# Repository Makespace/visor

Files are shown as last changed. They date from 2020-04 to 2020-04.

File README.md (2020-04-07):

# Makespace Visor

The documents covering the regulation, design and production of the Makespace Visor

For the high-level overview of this activity, see https://web.makespace.org/visor/

* _Requirements_ – The device specification, regulations and risk assessments
* _Design Files_ – The delve mask design files
* _Materials_ – The materials, BOM, and data sheets
* _Production_ – Manufacturing Standard Operating Procedure (SOP), Training and Worker/Batch Tracking
* _Documentation_ – The accompanying documentation and labelling for shipping

The _Manufacturing SOP_ and _Manufacturing SOP checklist_ documents found in the _production_ directory are the key documents describing the whole process, and the place to start if you want to learn about the activity.

The _Workstation single point lessons_ ppt is also useful to get a feel for the activities that need to be performed.

The _requirements_ directory is good reading for context on how the essential safety requirements mandated in regulations are fulfilled by the design and documentation. This is what is required when the UK government relaxed the rules on PPE for hospitals from ‘at least CE marked’ to ‘meet essential safety requirements’.

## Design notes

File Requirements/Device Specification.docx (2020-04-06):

# General Device Description & Intended Purpose

https://www.ncbi.nlm.nih.gov/pmc/articles/PMC5015006/

“Face shields are personal protective equipment devices that are used by many workers (e.g., medical, dental, veterinary) for protection of the facial area and associated mucous membranes (eyes, nose, mouth) from splashes, sprays, and spatter of body fluids. Face shields are generally not used alone, but in conjunction with other protective equipment and are therefore classified as adjunctive personal protective equipment. “

# Specifications for Product

Product Requirements

1. Face shield must have a single elasticated strap.
2. Doffing can be accomplished with a single hand.
3. Face shields must fit snugly to afford a good seal to the forehead area - forehead contact at least width of eyes. Contact surface soft foam or rubber, to reduce slippage during wearing.
4. Visors must not significantly distort vision. Normal font size text should be readable whilst wearing them.
5. Face shields should reach down to the chin and to the point of the ear, and seal to the forehead.
6. The face should be sufficiently rigid to not move around (creating noise or distortion) whilst walking.
7. The edges and corners or both the headband and visor should not be sharp such that they could rip gloves or cause injury. The staples must not touch the skin.
8. The visor should have sufficient clearance to the face for goggles and a face mask to be worn comfortably.
9. Visors should be resistant to fogging, either through coatings or ventilation.
10. The face shield is single use so does need to be sterilisable or resistant to cleaning products

For reference: https://docs.google.com/document/d/15k20PMe14_XQa-8kTA2G7nSIrF1bGSpc90_GM9H8yNI/edit

Cambridge University Hospitals NHS Foundation Trust Page 1 of 2 Prescription for Face Shield to be used during Coronavirus outbreak

Clinical Engineering Innovation Medical Physics and Clinical Engineering

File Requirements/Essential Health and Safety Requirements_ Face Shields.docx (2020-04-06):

# Essential Health and Safety Requirements: Face Shields

1. Purpose

Face shields are NOT a medical device:

https://assets.publishing.service.gov.uk/government/uploads/system/uploads/attachment_data/file/284505/Borderlines_with_medical_devices.pdf

Masks intended to protect the wearer, they are regulated as personal protective equipment and need to meet the regulations covering PPE products:

https://eur-lex.europa.eu/legal-content/EN/TXT/?uri=CELEX:32016R0425

In the current coronavirus outbreak regulations have been temporarily suspended to fast-track supplies of PPE to NHS staff and protect companies hit by COVID-19. PPE equipment is allowed to be placed on the market providing protection against COVID-19 which lack the CE mark onto the market provided products meet essential safety requirements.

https://www.gov.uk/government/news/regulations-temporarily-suspended-to-fast-track-supplies-of-ppe-to-nhs-staff-and-protect-companies-hit-by-covid-19

2. Scope

This document sets out the Essential Health and Safety Requirements in Annex II of the REGULATION (EU) 2016/425 OF THE EUROPEAN PARLIAMENT AND OF THE COUNCIL of 9 March 2016 on personal protective equipment and repealing Council Directive 89/686/EEC for face shields produced and manufactured by CEI for use within Addenbrookes to help prevent coronavirus (COVID-19)

3. Annex II: Essential Health and Safety Requirements

In addition to any of the measures specified in this document, a full risk assessment will be performed in order to identify the risks which apply to this PPE. This will include not only the intended use of the PPE, but also the reasonably foreseeable uses and where applicable, the health and safety of persons other than the user.

Essential Health and Safety Requirement | Method of fulfilment | Additional documentation (if applicable)

1. GENERAL REQUIREMENTS APPLICABLE TO ALL PPE
PPE must provide adequate protection against the risks against which it is intended to protect. | Face shields are designed to protect the face and eyes from liquid droplets that may contain viral particles. The plastic visors cover the full face and are impermeable to water. | Design Documentation
1.1. Design principles 1.1.1. Ergonomics PPE must be designed and manufactured so that, in the foreseeable conditions of use for which it is intended, the user can perform the risk-related activity normally whilst enjoying appropriate protection of the highest level possible. | The face shields are made of clear plastic to allow the user full visibility to perform their activities whilst providing appropriate protection. | Requirements Specification Design Documentation User Feedback / Clinical prescription
1.1.2. Levels and classes of protection 1.1.2.1. Optimum level of protection The optimum level of protection to be taken into account in the design is that beyond which the constraints imposed by the wearing of the PPE would prevent its effective use during the period of exposure to the risk or the normal performance of the activity. | The face shields are designed to be as large as possible to cover the entire face, without impacting activities. The flexible plastic allows for a close fit around the face and the foam along the top prevents droplets entering from above. Further attempts to make the design more fitted would limit the number of clinicians who it would fit and restrict normal activities. | Requirements Specification Design Documentation Risk File
1.1.2.2. Classes of protection appropriate to different levels of risk Where differing foreseeable conditions of use are such that several levels of the same risk can be distinguished, appropriate classes of protection must be taken into account in the design of the PPE. | Face shields are designed to meet the user requirements for use as specified by hospital guidance. Where specified in the hospital guidance and training documents additional or different PPE will be worn | Requirements Specification Design Documentation
1.2. Innocuousness of PPE 1.2.1. Absence of inherent risks and other nuisance factors PPE must be designed and manufactured so as not to create risks or other nuisance factors under foreseeable conditions of use. | Face masks are designed so that only a foam strip makes contact with the user's forehead. This is to maximise comfort and increase compliance. Face shields are designed to be similar to current PPE used by clinical staff in the hospital. | Requirements Specification Design Documentation User Feedback / Clinical Prescription
1.2.1.1. Suitable constituent materials The materials of which the PPE is made, including any of their possible decomposition products, must not adversely affect the health or safety of users. | Appropriate selection of materials and suppliers. Non toxic biocompatible materials selected. Materials will only make contact with non-broken skin. | Material Data sheets and supplier information
1.2.1.2. Satisfactory surface condition of all PPE parts in contact with the user Any part of the PPE that is in contact or is liable to come into contact with the user when the PPE is worn must be free of rough surfaces, sharp edges, sharp points and the like which could cause excessive irritation or injuries. | Plastic shields will be cut using a laser cutter and checked for rough or sharp edges. If found these will be removed by an appropriate method (e.g. x-acto knife) | Manufacturing Work Instruction - Quality Check
1.2.1.3. Maximum permissible user impediment Any impediment caused by PPE to the actions to be carried out, the postures to be adopted and sensory perceptions shall be minimised. Furthermore, use of the PPE must not engender actions which might endanger the user. | Face shields will be designed to be similar to those that clinicians are already familiar with wearing. There shall be no increased impediments. Elastic straps will not be too tight that users will feel the need to reposition their face shields during use. They will not be too loose that the face shield could slip down. | Requirements Specification Device Design Documentation Risk File User Feedback / Clinical Prescription Device Verification and Validation
1.3. Comfort and effectiveness 1.3.1. Adaptation of PPE to user morphology PPE must be designed and manufactured in such a way as to facilitate its correct positioning on the user and to remain in place for the foreseeable period of use, bearing in mind ambient factors, the actions to be carried out and the postures to be adopted. For this purpose, it must be possible to adapt the PPE to fit the morphology of the user by all appropriate means, such as adequate adjustment and attachment systems or the provision of an adequate range of sizes. | The use of compressible foam strip and elastic strap allow the face shields to fit comfortably on users of varying morphology | Device Design Documentation Risk File Device Verification and Validation
1.3.2. Lightness and strength PPE must be as light as possible without prejudicing its strength and effectiveness. PPE must satisfy the specific additional requirements in order to provide adequate protection against the risks for which it is intended and PPE must be capable of withstanding environmental factors in the foreseeable conditions of use. | The face shields are designed to protect users against liquid droplets. In typical use it is not anticipated that they will come into contact with any large mechanical forces. The plastic is therefore as thin as possible to be as light as possible and flex easily around the users head.The plastic will not shatter if a foreseeable force is applied. | Risk File Device Design Documentation Materials Data Sheets
1.3.3. Compatibility of different types of PPE intended for simultaneous use If the same manufacturer places on the market several PPE models of different types in order to ensure the simultaneous protection of adjacent parts of the body, they must be compatible. | User feedback - Sadaf & Christine feedback that it fits over goggles, glasses, masks | Device Verification and Validation
1.3.4. Protective clothing containing removable protectors Protective clothing containing removable protectors constitutes PPE and shall be assessed as a combination during conformity assessment procedures. | n/a

1.4. Manufacturer's instructions and information

In addition to the name and address of the manufacturer, the instructions that must be supplied with the PPE must contain all relevant information on:

A. instructions for storage, use, cleaning, maintenance, servicing and disinfection. Cleaning, maintenance or disinfectant products recommended by manufacturers must have no adverse effect on the PPE or the user when applied in accordance with the relevant instructions;
B. performance as recorded during relevant technical tests to check the levels or classes of protection provided by the PPE;
C. where applicable, accessories that may be used with the PPE and the characteristics of appropriate spare parts;
D. where applicable, the classes of protection appropriate to different levels of risk and the corresponding limits of use;
E. where applicable, the month and year or period of obsolescence of the PPE or of certain of its components;
F. where applicable, the type of packaging suitable for transport;
G. the significance of any markings (see point 2.12);
H. the risk against which the PPE is designed to protect;
I. the reference to this Regulation and, where applicable, the references to other Union harmonisation legislation;
J. the name, address and identification number of the notified body or bodies involved in the conformity assessment of the PPE;
K. references to the relevant harmonised standard(s) used, including the date of the standard(s), or references to the other technical specifications used;
L. the internet address where the EU declaration of conformity can be accessed.

The information referred to in points (i), (j), (k) and (l) need not be contained in the instructions supplied by the manufacturer if the EU declaration of conformity accompanies the PPE.

Instructions for Use (on outer packaging of each face shield).

Label Content (on face shield)

Manufacturer's Instructions and Information

2. ADDITIONAL REQUIREMENTS COMMON TO SEVERAL TYPES OF PPE
2.3. PPE for the face, eyes and respiratory system Any restriction of the user's face, eyes, field of vision or respiratory system by the PPE shall be minimised. The screens for those types of PPE must have a degree of optical neutrality that is compatible with the degree of precision and the duration of the activities of the user. If necessary, such PPE must be treated or provided with means to prevent misting-up. Models of PPE intended for users requiring sight correction must be compatible with the wearing of spectacles or contact lenses. | Face shields are transparent to allow for full visibility. Testing on volunteers to ensure that they do not fog up or restrict vision | Requirements Specification Device Design Documentation Risk file Materials Data sheets Device Verification and Validation

3.10.2. Protection against cutaneous and ocular contact

PPE intended to prevent the surface contact of all or part of the body with substances and mixtures which are hazardous to health or with harmful biological agents must be capable of preventing the penetration or permeation of such substances and mixtures and agents through the protective integument under the foreseeable conditions of use for which the PPE is intended.

To this end, the constituent materials and other components of those types of PPE must be chosen or designed and incorporated so as to ensure, as far as possible, complete leak-tightness, which will allow where necessary prolonged daily use or, failing this, limited leak-tightness necessitating a restriction of the period of wear.

Where, by virtue of their nature and the foreseeable conditions of their use, certain substances and mixtures which are hazardous to health or harmful biological agents possess high penetrative power which limits the duration of the protection provided by the PPE in question, the latter must be subjected to standard tests with a view to their classification on the basis of their performance. PPE which is considered to be in conformity with the test specifications must bear a marking indicating, in particular, the names or, in the absence of the names, the codes of the substances used in the tests and the corresponding standard period of protection. The manufacturer's instructions must also contain, in particular, an explanation of the codes (if necessary), a detailed description of the standard tests and all appropriate information for the determination of the maximum permissible period of wear under the different foreseeable conditions of use.

Face shields are designed to protect the face and eyes from liquid droplets that may contain viral particles. The plastic visors cover the full face and are impermeable to water.

Risk File

Monitoring compliance with and the effectiveness of this document

This process forms part of a quality system accredited to International Standard EN ISO 9001:2015, EN ISO 13485:2016 and BS 70000:2017. The effectiveness of the process will be monitored in accordance with the methods given in the Quality Manual (CE-QS-QAM-4).

Equality and diversity statement

This document complies with the Cambridge University Hospitals NHS Foundation Trust service equality and diversity statement.

Disclaimer

It is your responsibility to check against the electronic library that this printed out copy is the most recent issue of this document.

Document management

Approval:
MDAG approval:
Owning department: | Clinical Engineering Innovation
Author(s): | Sarah Greasley
Pharmacist: | n/a
File name: | Device Verification and Validation
Supersedes: | n/a
Version number: | 1.0 | Review date: | n/a
Local reference: | | Document ID:

Cambridge University Hospitals NHS Foundation Trust Essential Health and Safety Requirements: Face Shields

Clinical Engineering Innovation Medical Physics and Clinical Engineering

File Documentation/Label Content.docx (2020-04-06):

# Label Content

# Product Label

- For each product

Full Face Shield

Personal Protective Equipment

Non-sterile, disposable

MS-yy/mm/dd-’Initials’

Clinical Engineering, Box 152, Addenbrooke's Hospital, Cambridge, CB2 0QQ

# Shipping Label

- For each box of product

Full Face Shield x 24

Packed on: yy/mm/dd

By: “Initials”

Manufactured for: Clinical Engineering, Box 152, Addenbrooke's Hospital, Cambridge, CB2 0QQ

Shipping Address

# Non-Conformance Label

- An additional label for boxes of product where some or all of the products carry an increased risk of contamination with COVID-19 due to some non-conformance with the Manufacturing SOP

Full Face Shield x 24

Packed on: yy/mm/dd

Health & Safety Notice:

DO NOT UNPACK UNTIL packing date + 5 days

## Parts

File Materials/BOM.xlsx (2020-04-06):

Material | Thickness/width (mm) | Size (mm) each | Notes | Suppliers / status / risk | Order Status | Example Link | Cost |  | 1K cost | 2K cost
PLASTIC
PET | 0.18 | 330x230 | 0.1-0.5 closer to 0.18mm the better), at least 330x230mm |  |  |  |  |  | 0.76 | 0.38
ELASTIC
Roll of elastic | 25 | 0.345metres | Latex free difficult to source - best to check with suppliers |  |  | https://www.amazon.co.uk/dp/B079TMHSZP/ref=pe_3187911_189395841_TE_3p_dp_1?pldnSite=1 | Donated but worth £10.89 |  | 0.25 | 0.25
FOAM - PU adhesive backed
PU Foam | 25x25mm | 225 | ~30kgs/m^3 |  |  | https://www.efoam.co.uk/acoustic-soundproofing-foam.php | £185 for 3 x 100 cm x 200 cm sheet plus ~120 delivery |  | 0.205 | 0.205
Plastic packaging
Plastic bags to wrap finished PPE |  |  | 305mm x 406mm self sealing 1100 on order |  |  | https://www.amazon.co.uk/gp/product/B01AQO7PRU/ref=ppx_yo_dt_b_asin_title_o00_s00?ie=UTF8&psc=1 | £6.67 / 100 | 73.37 | 0.0667 | 0.103385
OTHER
Staples | 26/6 | 2 per | Standard Rapid 26/6 - stationary weight staples |  |  | https://www.amazon.co.uk/gp/product/B004VUV8ZQ/ref=ppx_yo_dt_b_asin_title_o02_s00?ie=UTF8&psc=1 | £1.63 / 5000 |  | 0.0042
Boxes for shipment to Hospital |  | 2020-01-24 | they sit flat, so 330x230x26mm each, though could nest to be 330x230x13 average
Packing tape |  | 1m | 6 x 65m x 50mm clear packing tape |  |  | https://www.amazon.co.uk/gp/product/B01ABXS3ZO/ref=ppx_yo_dt_b_asin_title_o02_s00?ie=UTF8&psc=1 | £6.07 / 360m
Labels
Anitfog |  |  |  |  |  | https://www.amazon.co.uk/Cressi-Anti-Fog-Spray-60-ML/dp/B004TRQAEU | £7.98 / 2 bottles
Disinfectant
Bleach | 1 bottle | 1 litre | Domestos - donated |  |  | https://www.epa.gov/pesticide-registration/list-n-disinfectants-use-against-sars-cov-2 | £1 per bottle? |  | 0.005
Cleaner
Multipurpose Cleaner | 1 bottle | 5 litre | 5 Star Multi Purpose Cleaner 5 Litre (https://www.amazon.co.uk/gp/product/B00PFT0MZ4/ref=ppx_yo_dt_b_asin_title_o08_s00?ie=UTF8&psc=1) |  |  | https://www.amazon.co.uk/gp/product/B00PFT0MZ4/ref=ppx_yo_dt_b_asin_title_o08_s00?ie=UTF8&psc=1 | £5.62 |  | 0.00562
Cleaning Cloths
Center feed cloths | 2 rolls | 350 sheet |  |  |  | https://www.amazon.co.uk/gp/product/B00BTHABGG/ref=ppx_yo_dt_b_asin_title_o06_s00?ie=UTF8&psc=1 | £30.78/2 rolls |  | 0.03078
gloves |  |  |  |  |  |  |  |  | 0.027
visors
masks
 |  |  |  |  |  |  | £40/50 |  | 0.04
overalls
 |  |  |  |  |  |  | £5 each |  | 0.05
Reference:
https://discourse.southlondonmakerspace.org/t/3d-printing-laser-cutting-medical-face-shields-may-become-a-thing-imminently-lets-be-ready/16736/9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
https://www.delve.com/assets/documents/Open-Source-Face-Shield-Drawing.pdf
Clear Shield | 1 | £0.76
Elastic Headband | 1 | £0.25
Brow Foam | 1 | £0.20
Staples | 4 | £0.01
Plastic Bag | 1 | £0.07
Label | 1 | £0.04
Shipping Box | 2020-01-10 | £0.00
Batch sheet | 2020-01-10 | £0.01
Shipping label | 2020-01-10 | £0.01
 |  | £1.35 | Full cost - assumes costs of all material purchased and 1K shields manufactured
2K visor costs
Clear Shield | 1 | £0.38
Elastic Headband | 1 | £0.00
Brow Foam | 1 | £0.20
Staples | 4 | £0.02
Plastic Bag | 1 | £0.10
Label | 1 | £0.04
Shipping Box | 2020-01-10 | £0.00
Batch sheet | 2020-01-10 | £0.01
Shipping label | 2020-01-10 | £0.01
 |  | £0.77 | Full cost - assumes costs of all material purchased and 2K shields manufactured
Manufacturing Materials
Gloves |  | £0.03
Masks |  | £0.04
Overalls |  | £0.05
Cleaning materials |  | £0.01
Disinfecting materials |  | £0.01
Cleaning cloths |  | £0.03
Sundries (Ducktape etc) |  | £0.03
 |  | £0.18 | Nominal cost - assumes material used up to make 1K or 2K shields
 |  | £1.54 | Cost per shield for 1K shields
 |  | £0.95 | Cost per shield for 2K shields

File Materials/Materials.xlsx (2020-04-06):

Purpose: | Document materials used. Where Risk File highlights risks associated with material choice, this document relates those risks with evidence from the data sheet that the risk has/has not been controlled.
Component | Selected Material | DataSheet in folder? | Risk ID | Risk Control Measures | Documentation of risk control | Link
Visor | Polyester film (PET) | No | n/a
Foam | Open celled polyurethane foam | Yes | FV06 | Medical grade foam, tested on users for 4hrs with no adverse effects, | Data sheet, Design verification & validation | https://www.efoam.co.uk/foam-for-face-masks-shields-visors-ppe.php
 |  | Yes | FV07 | Medical grade foam, tested on users for 4hrs with no adverse effects, | Data sheet, Design verification & validation
Elastic | Woven loom elastic, 25mm, black | Yes | FV15 | Product confirmed by manufacturer to contain latex in elastic but not in covering for elastic. Risk controlled through product labelling. | Data sheet, Product Labels | https://www.williamgee.co.uk/shop/woven-loom-elastic-25mm/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
 |  | Yes | FV16 | Product confirmed by manufacturer to contain latex in elastic but not in covering for elastic. Risk controlled through product labelling. | Data sheet, Product Labels
 |  | Yes | FV17 | Product confirmed by manufacturer to contain latex in elastic but not in covering for elastic. Risk controlled through product labelling. | Data sheet, Product Labels

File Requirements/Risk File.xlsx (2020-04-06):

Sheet: Title
Medical Physics and Clinical Engineering |  |  |  | Addenbrookes Hospital
Clinical Engineering / R&D
Risk File |  |  |  | CE-ER-FRM-22
 |  | Product Identification | DELVE Visor
 |  | Document Q-Pulse reference
 |  | Doc. Name | Risk File - Delve Visor
 |  | Mandatory Supporting Documents | Q-Pulse reference
 |  | Risk Management Process
 |  | Risk Plan
 |  | Risk Report
 | Product description and intended use
 | Transparent visor covering the face, held in place by an elastic band, and cushioned on the forehead by a foam strip. The visor is considered to be PPE for use by clinical staff in close contact with patients who may have or definitely have COVID-19. The visor: - prevents droplets containing virus being projected onto the skin and mucous membranes of the user's face - reduces probability that direct contact is made with the face by patients with COVID-19 - prevents an asymptomatic, but infected, user projecting particles onto patients. The visor does not prevent small aerosol particles that come around the edges of the visor being entrained in the user's in-breath, and is therefore not considered to provide complete protection and shoudl be usefd tgeter with other appropriate PPE.
Cambridge University Hospitals NHS Foundation Trust |  |  |  |  | Page 1 of 4
This document complies with the Cambridge University Hospitals NHS Foundation Trust service Equality and Diversity statement and must be read in conjunction with Addenbrookes Hospital Policies & Procedures. It is your responsibility to check against the electronic library that this printed out copy is the most recent issue of this document. All changes required should be submitted via Q-Pulse Document module (Change request).
Filename: 008_Risk Evaluation Table
Document No.: CE-ER-FRM-15 |  |  | Version No.: 5 | Active on Q-Pulse & Published

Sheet: Revision Table
Document History
Date | Identification | Description | Name
26/03/2020 | 1.0 | Created | AB

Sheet: Risk Evaluation Criteria
CUH Risk management strategy and policy 2019-2019
 | CUH Risk management strategy and policy 2019-2020
Source | CUH Risk management strategy and policy 2019-2020, http://merlin/Lists/DMSRecords/DispRecordTabsDoc.aspx?ID=18427
Adaptations | The risk scoring matrix and grading system has been adapted to enable the CEI team to better track and manage risks that are yet to be determined, or cannot be determined.
Notes | Risk evaluation is for injury or damage to the health of people, or damage to property or the environment, and does include risks surrounding data security. It should NOT consider project or financial impacts. These should instead be considered in the Project Viability Assessment.
 | Risk Evaluation
 | Severity Score |  | Likelihood Score |  |  |  |  |  |  | Grading Risk
 |  |  | 1 | 2 | 3 | 4 | 5 | TBD | CBD | 1-3 | Low risk | No action required
 |  |  | Rare | Unlikely | Possible | Likely | Almost Certain | To be determined | Cannot be determined | 4-6 | Moderate risk | Risk reduction if practicable
 | 1 | Negligible | 1 | 2 | 3 | 4 | 5 | 25 | 25 | 8-12 | High risk | Risk reduction if practicable, cost benefit analysis required for risks that cannot be practibably lowered
 | 2 | Minor | 2 | 4 | 6 | 8 | 10 | 25 | 25 | 15-25 | Significant risk | Unnacceptable risk
 | 3 | Moderate | 3 | 6 | 9 | 12 | 15 | 25 | 25 | TBD | To be determined | Activities required to define risk likelihood or severity
 | 4 | Major | 4 | 8 | 12 | 16 | 20 | 25 | 25 | CBD | Can't be determined | Treat as unnacceptable and define control measures, or justify lower risk score
 | 5 | Catastrophic | 5 | 10 | 15 | 20 | 25 | 25 | 25
 | TBD | To be determined | 25 | 25 | 25 | 25 | 25 | 25 | 25
 | CBD | Cannot be determined | 25 | 25 | 25 | 25 | 25 | 25 | 25
 | Likelihood Score
 |  | 1 | 2 | 3 | 4 | 5
 | Descriptor | Rare | Unlikely | Possible | Likely | Almost Certain
 | Frequency | This will probably never happen/recur | Do not expect it to happen/recur but it is possible | Might happen or recur occasionally | Will probably happen/recur but it is not a persisting issue | Will undoubtedly happen/recur,possibly frequently
 | Severity Score
 |  | 1 | 2 | 3 | 4 | 5
 | Descriptor | Negligible | Minor | Moderate | Major | Catastrophic
 | Impact on the safety of patients, staff or public (physical/psychological harm) | Minimal injury requiring no/minimal intervention or treatment. | Minor injury or illness, requiring minor intervention. Increase in length of hospital stay by 1-3 days Requiring time off work for >3 days | Moderate injury requiring professional intervention. Requiring time off work for 4-14 days Increase in length of hospital stay by 4-15 days RIDDOR/agency reportable incident An event which impacts on a small number of patients. | Major injury leading to long-term incapacity/disability. Increase in length of hospital stay by >15 days. Mismanagement of patient care with longterm effects. Requiring time off work for >14 days | Incident leading to death. Multiple permanent injuries or irreversible health effects. An event which impacts on a large number of patients.
 | Quality of treatment | Peripheral element of treatment or service suboptimal Informal complaint/inquiry | Overall treatment or service suboptimal Single failure to meet internal standards | Treatment or service has significantly reduced in effectiveness Repeated failure to meet internal standards | Non-compliance with national standards with significant risk to patients if unresolved Multiple complaints/ independent review Low performance rating Critical report | Totally unacceptable level or quality of treatment/service Gross failure of patient safety if findings not acted on Inquest/ombudsman inquiry Gross failure to meet national standards
 | Personal information | No risk to confidential staff or patient data | Occassional/one-off cases of personal data exposure within CUH | Data exposure within CUH | Public exposure of personal data Exposure of personal data to entities who may use that data against the best interest of the person to whom the data belongs | Large scale public exposure of personal data Exposure of personal data to entities who will use that data against the best interest of the person to whom the data belongs
 | Envrionmental impact | Minimal or no impact on the environment | Minor impact on environment | Moderate impact on environment | Major impact on environment | Catastrophic impact on environment
 | Environmental impact | Minimal or no impact on the environment | Minor impact on environment | Moderate impact on environment | Major impact on environment | Catastrophic impact on environment

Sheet: Benefit Evaluation Criteria
008_Risk Evaluation Table
 | Benefit Evaluation Criteria
Source | Developed by CEI
Adaptations | n/a
Notes | Benefit evaluation is for assessing impact on positive impact on clinical outcome, the patient’s quality of life, outcomes related to diagnosis, positive impact from diagnostic devices on clinical outcomes, or positive impact on public health or patient management. It should NOT consider project or financial impacts. These should instead be considered in the Project Viability Assessment.
 | Risk Evaluation
 | Benefit Size Score |  | Certainty Score |  |  |  |  | Grading Risk
 |  |  | 1 | 2 | 3 | 4 | 5 | 15-25 | Large, clear benefit
 |  |  | Very unlikely to be realised | Unlikely | Possible | Likely | Almost Certain | 2020-10-12 | Reasonable benefit
 | 1 | Negligible | 1 | 2 | 3 | 4 | 5 | 2020-05-09 | Small benefit
 | 2 | Minor | 2 | 4 | 6 | 8 | 10 | 2020-01-04 | Very little benefit
 | 3 | Moderate | 3 | 6 | 9 | 12 | 15
 | 4 | High | 4 | 8 | 12 | 16 | 20
 | 5 | Very High | 5 | 10 | 15 | 20 | 25
 | Likelihood Score
 |  | 1 | 2 | 3 | 4 | 5
 | Descriptor | Rare | Unlikely | Possible | Likely | Almost Certain
 | Frequency | Possible but quite unlikely outcome of the project/extremely uncertain outcome of the project | Possible outcome of the project, but uncertain | Possible outcome of the project | A likely outcome of the project | Will undoubtedly happen as an outcome of the project if completed successfully
 | Impact Score
 |  | 1 | 2 | 3 | 4 | 5
 | Descriptor | Negligible | Minor | Moderate | High | Very High
 | Medical Benefit | No measurable impact on medical outcomes No measurable impact on patient experience Minor anecdotal benefit | Minor measurable impact on medical outcomes Minor measurable impact on patient experience Moderate anecdotal benefit | Moderate measurable impact on medical outcomes Moderate measurable impact on patient experience Large anecdotal benefit (e.g. patients happy to engage with a home treatment method where they otherwise wouldn't) | Significant measurable impact on key medical outcomes Significant measurable impact on patient experience | Measurable life-saving impact
 | Scale of impact | Hospital, short term or one-off Less than 100 patients per year | Hospital Hundreds of patients per year | Hospital or regional Thousands of patients per year | National 10s of thousands of patients per year | International 100s of thousands of patients affected per year
 | Clinical benefit | No measurable impact | Minor increase in number of patients treated for a given resource (e.g. reduced hospital stay Minor decrease in resource required to treat a given number of patients (lower cost per intervention, reduction in consultant time per appointment) Minor improvement in service quality (e.g. speed of diagnosis, error reduction) | Moderate increase in number of patients treated for a given resource (e.g. reduced hospital stay Moderate decrease in resource required to treat a given number of patients (lower cost per intervention, reduction in consultant time per appointment) Moderate improvement in service quality (e.g. speed of diagnosis, error reduction) | Large increase in number of patients treated for a given resource (e.g. reduced hospital stay Large decrease in resource required to treat a given number of patients (lower cost per intervention, reduction in consultant time per appointment) Large improvement in service quality (e.g. speed of diagnosis, error reduction) | Transformative increase in number of patients treated for a given resource (e.g. reduced hospital stay Transformative decrease in resource required to treat a given number of patients (lower cost per intervention, reduction in consultant time per appointment) Transformative improvement in service quality (e.g. speed of diagnosis, error reduction)

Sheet: Overall Benefit Risk
008_Risk Evaluation Table
Benefit Risk Summary
Source | Developed by CEI
 | Overall Benefit: | 25
 | Residual Risk: | 10
 | Summary of benefit: | This device would enable Addenbrookes staff to access face visors when they otherwise would not have access. The project will supply 100,000 disposable face visors, where otherwse the trust would have none. Face visors are a key piece of PPE required to protect staff from liquid droplets transmitting COVID-19 from impacting mucous membranes and skin of the face.
 | Summary of risk: | There is a small residual risk that COVID-19 could be transmitted from manufacturer to staff, due to the short timeframe between manufacture and use. COVID-19 can survive on plastic surfaces fro at least 3 days, potentially longer. There is a small risk that someone with a severe latex allergy may be severely harmed through use of this product.
 | Actions summary: | If applicable summarise intended actions (for example, to reduce the risk)
Optional: Benefit-risk summary for current state-of-the-art
Source | If the device being assessed is intended to replace/improve upon the current state of the art, it can strengthen the benefit-risk analysis to compare it to the benefit-risk profile of the device representing the current state-of-the-art or best practice. In situations where there is no obvious comparative device, this type of analysis may not be appropriate. “State-of-the-art” embodies what is currently and generally accepted as good practice in technology and medicine. The state of the art does not necessarily imply the most technologically advanced solution.
 | Overall Benefit: | 0
 | Residual Risk: | 0
 | Summary of benefit: | Summarise the overall clinical/medical benefit being delivered
 | Summary of risk: | Summarise the overall clinical/medical risk being considered
 | Actions summary: | If applicable summarise intended actions (for example, to reduce the risk)
 | NOT APPLICABLE - product proposal is due to absence of availability of state-of-the-art

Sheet: Device Benefit Evaluation
008_Risk Evaluation Table
Benefit Evaluation Table for medical and clinical benefits associated with the medical device
Source | Developed by CEI
 | Overall Benefit: | 25 | Evaluate overall residual medical/clinical benefit. This can be estimated as the largest single RPN score.
S = severity, L = likelihood, RPN = Risk Priority Number
Unique ID for hazard plus control measure - useful for referencing hazards in other documents | Brief note explaining benefit | Brief note explaining consequence of benefit | Define any investigatory activities/follow up actions when it is too early to define impact/likelihood | Impact | Likelihood | Score
ID | Benefit | Consequence | Investigatory activities required | S | L | RPN
FV01 | Face visors are available for staff requiring them. Without this project, staff will go without face visors. | Reduction of staff risk in contracting COVID-19 |  | 5 | 5 | 25
 |  |  |  |  |  | 0
 |  |  |  |  |  | 0
 |  |  |  |  |  | 0
 |  |  |  |  |  | 0
 |  |  |  |  |  | 0
 |  |  |  |  |  | 0
 |  |  |  |  |  | 0
 |  |  |  |  |  | 0
 |  |  |  |  |  | 0
 |  |  |  |  |  | 0
 |  |  |  |  |  | 0
 |  |  |  |  |  | 0
 |  |  |  |  |  | 0
 |  |  |  |  |  | 0
 |  |  |  |  |  | 0
 |  |  |  |  |  | 0
 |  |  |  |  |  | 0
 |  |  |  |  |  | 0
 |  |  |  |  |  | 0
 |  |  |  |  |  | 0
 |  |  |  |  |  | 0
 |  |  |  |  |  | 0
 |  |  |  |  |  | 0
 |  |  |  |  |  | 0
 |  |  |  |  |  | 0
 |  |  |  |  |  | 0
 |  |  |  |  |  | 0
 |  |  |  |  |  | 0
 |  |  |  |  |  | 0
 |  |  |  |  |  | 0
 |  |  |  |  |  | 0
 |  |  |  |  |  | 0
 |  |  |  |  |  | 0
 |  |  |  |  |  | 0
 |  |  |  |  |  | 0
 |  |  |  |  |  | 0
 |  |  |  |  |  | 0
 |  |  |  |  |  | 0
 |  |  |  |  |  | 0
 |  |  |  |  |  | 0
 |  |  |  |  |  | 0
 |  |  |  |  |  | 0
 |  |  |  |  |  | 0
 |  |  |  |  |  | 0
 |  |  |  |  |  | 0
 |  |  |  |  |  | 0
 |  |  |  |  |  | 0
 |  |  |  |  |  | 0
 |  |  |  |  |  | 0
 |  |  |  |  |  | 0
 |  |  |  |  |  | 0
 |  |  |  |  |  | 0
 |  |  |  |  |  | 0
 |  |  |  |  |  | 0
 |  |  |  |  |  | 0
 |  |  |  |  |  | 0
 |  |  |  |  |  | 0
 |  |  |  |  |  | 0
 |  |  |  |  |  | 0
 |  |  |  |  |  | 0
 |  |  |  |  |  | 0

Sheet: Device Risk Evaluation
Risk Evaluation Table for health hazards associated with the medical device that may impact users or patients
Scope: | injury or damage to the health of people, or damage to property or the environment
Source | Developed by CEI
 | Residual Risk: | 10 | Evaluate overall residual medical/clinical risk following the process described in the Risk Management Process CE-ER-PRO-14
 | Explanation: | Severity of overall risk is high, as COVID-19 could be transmitted to frontline medical staff via the PPE. However, the risks are being managed through a number of measures to make this unlikely.
S = severity, L=likelihood
Unique ID for hazard plus control measure | Brief note describing hazard | Brief note expalining impact/consequences of hazard | Severity | Likelihood | Score | Define any investigatory activities/follow up actions when it is too early to define a risk control activity | Define activities to control risk (or summarise existing evidence) | Provide a Q-Pulse reference, or location reference to the Technical File | Provide a date of completion for risk control activitie, to confim the activity has been completed | Severity | Likelihood | Score | Detail outcome - is the risk acceptable? If not, is a further risk control measure required (please enter the same hazard with a different ID and repeat the risk evaluation and control prcoess)? Alternatively, is a risk benefit analysis required? | Optional - tick if a risk/benefit is required | Please summarise the outcome of the risk/benefit analysis | If not in this document, please supply a Q-Pulse reference or location reference to the Technicla Filefor location of risk-benefit analysis
ID | Hazard | Consequence | S | L | RPN | Further activities required | Risk Control Measures | Supporting Documentation | Date carried out dd/mm/yyyy | S2 | L2 | RPN2 | Outcome | Risk/Benefit required? | Risk Benefit Outcome | Supporting Documentation2
FV01 | Viral transmission from manufacturer to user via persistence of virus on plastic visor materials | Infection of clinical staff member, who may infect other staff or patients - worst possible consequence is death | 5 | 3 | 15 | Check longevity of viable virus in literature | Process control to ensure risk of transmission from manufacturer to product is minimised | Manufacturing SOP | 29/03/2020 | 5 | 1 | 5 | No further risk reduction practicable for this design. One further risk reduction option is to identify a design that is suitable for cleaning/sterilisation on arrival on site. | Yes | Likelihood of infection through not wearing a visor is probable. The likelihood of infection from a visor subject to these process controls would be extremely rare.
FV02 | Viral transmission due to presence of virus on plastic material for visor before arrival at the manufacturing facility. Transmission to manufacturing staff, or to clinical staff. | Infection of clinical staff member, who may infect other staff or patients - worst possible consequence is death | 5 | 3 | 15 | Risk assess different material supply options | Prevention through material handling controls | Manufacturing SOP | 29/03/2021 | 5 | 1 | 5 | No further risk reduction practicable for this design. One further risk reduction option is to identify a design that is suitable for cleaning/sterilisation on arrival on site. | Yes | Likelihood of infection through not wearing a visor is probable. The likelihood of infection from a visor subject to these process controls would be extremely rare.
FV03 | Viral transmission due to presence of virus on foam material before arrival at the manufacturing facility. Transmission to manufacturing staff, or to clinical staff. | Infection of clinical staff member, who may infect other staff or patients - worst possible consequence is death | 5 | 3 | 15 | Risk assess different material supply options | Prevention through material handling controls | Manufacturing SOP | 29/03/2022 | 5 | 1 | 5 | No further risk reduction practicable for this design. One further risk reduction option is to identify a design that is suitable for cleaning/sterilisation on arrival on site. | Yes | Likelihood of infection through not wearing a visor is probable. The likelihood of infection from a visor subject to these process controls would be extremely rare.
FV04 | Viral transmission due to presence of virus on elastic material before arrival at the manufacturing facility. Transmission to manufacturing staff, or to clinical staff. | Infection of clinical staff member, who may infect other staff or patients - worst possible consequence is death | 5 | 3 | 15 | Risk assess different material supply options | Prevention through material handling controls | Manufacturing SOP | 29/03/2023 | 5 | 1 | 5 | No further risk reduction practicable for this design. One further risk reduction option is to identify a design that is suitable for cleaning/sterilisation on arrival on site. | Yes | Likelihood of infection through not wearing a visor is probable. The likelihood of infection from a visor subject to these process controls would be extremely rare.
FV05 | Viral transmission due to presence of virus on packaging material before arrival at the manufacturing facility. Transmission to manufacturing staff, or to clinical staff. | Infection of clinical staff member, who may infect other staff or patients - worst possible consequence is death | 5 | 3 | 15 | Risk assess different material supply options | Prevention through material handling controls | Manufacturing SOP | 29/03/2024 | 5 | 1 | 5 | No further risk reduction practicable for this design. One further risk reduction option is to identify a design that is suitable for cleaning/sterilisation on arrival on site. | Yes | Likelihood of infection through not wearing a visor is probable. The likelihood of infection from a visor subject to these process controls would be extremely rare.
FV06 | Foam irritates skin | Skin damage | 2 | 3 | 6 |  | Ensure material selected is appropriate for skin contact up to 4 hr | Data sheet | 2020-01-04 | 1 | 1 | 1 | Acceptable | No
FV07 | Foam irritates skin | clinical staff stop wearing mask | 5 | 2 | 10 |  | Ensure material selected is appropriate for skin contact up to 4 hrs | Data sheet | 2020-01-04 | 5 | 1 | 5 | No further risk reduction practicable | Yes | Likelihood of infection through not wearing a visor is highly likely. The likelihood of infection from a visor that is removed due to discomfort is also highly likely. Having the mask does not worsen the risk profile compared to the baseline situation.
FV08 | Droplets impact facial skin despite wearing visor | Infection, death | 5 | 2 | 10 |  | Dimensions of mask match or exceed predicate device - height above face, below face, width, extent of curvature | Design verification & validation | 2020-01-04 | 5 | 1 | 5 | No further risk reduction practicable | Yes | This design of mask provides the same or better protection than CE marked designs.
FV09 | Mask fogs up during use | clinical staff stop wearing mask | 5 | 2 | 10 | Evaluate need for anti-fog | Testing for 4hrs whilst wearing FFP3 mask | Design verification & validation | 2020-01-04 | 5 | 1 | 5 | No further risk reduction practicable | Yes | Likelihood of infection through not wearing a visor is highly likely. The likelihood of infection from a visor that is removed due to discomfort is also highly likely. Having the mask does not worsen the risk profile compared to the baseline situation.
FV10 | Mask does not fit face properly | clinical staff stop wearing mask | 5 | 2 | 10 | Initial evaluation by range of staff required - could we put a QR code on visor to a GoogleForm? | Testing with a range of different head size users | Design verification & validation | 2020-01-04 | 5 | 1 | 5 | No further risk reduction practicable | Yes | Likelihood of infection through not wearing a visor is highly likely. The likelihood of infection from a visor that is removed due to discomfort is also highly likely. Having the mask does not worsen the risk profile compared to the baseline situation.
FV12 | Mask is uncomfortable by design | clinical staff stop wearing mask | 5 | 2 | 10 | Initial evaluation by range of staff required - could we put a QR code on visor to a GoogleForm? | Testing for 4hrs whilst wearing FFP3 mask | Design verification & validation | 2020-01-04 | 5 | 1 | 5 | No further risk reduction practicable | Yes | Likelihood of infection through not wearing a visor is highly likely. The likelihood of infection from a visor that is removed due to discomfort is also highly likely. Having the mask does not worsen the risk profile compared to the baseline situation.
FV13 | Mask is uncomfortable due to sharp edges or staples | clinical staff stop wearing mask | 5 | 2 | 10 |  | Quality control during manufacturing process | Manufacturing SOP | 29/03/2024 | 5 | 1 | 5 | No further risk reduction practicable | Yes | Likelihood of infection through not wearing a visor is highly likely. The likelihood of infection from a visor that is removed due to discomfort is also highly likely. Having the mask does not worsen the risk profile compared to the baseline situation.
FV14 | Non-viral infection of clinical staff by face sheild | Staff sickness - possibility of passing on to patient | 4 | 2 | 8 | Risk assess different material supply options | Prevention through material selction/storage controls | Manufacturing SOP | 29/03/2024 | 4 | 1 | 4 | Acceptable | No
FV15 | Elastic contains latex | Skin damage | 2 | 2 | 4 |  | First, try to source latex free elastic. If not possible, mitigate through selecting elastic where the latex material is enclosed thereby unlikely to come into contact with skin, and clearly label the product stating that the elastic contains latex. | Data sheet Product Labels | 2020-01-04 | 2 | 1 | 2 | Acceptable | No
FV16 | Elastic contains latex | irritates skin, clinical staff stop wearing mask | 5 | 1 | 5 |  | First, try to source latex free elastic. If not possible, mitigate through selecting elastic where the latex material is enclosed thereby unlikely to come into contact with skin, and clearly label the product stating that the elastic contains latex. | Data sheet Product Labels | 2020-01-04 | 5 | 1 | 5 | No further risk reduction practicable | Yes | Likelihood of infection through not wearing a visor is highly likely. The likelihood of infection from a visor that is removed due to discomfort is also highly likely. Having the mask does not worsen the risk profile compared to the baseline situation.
FV17 | Elastic contains latex | Severe allergic reaction | 5 | 1 | 5 |  | First, try to source latex free elastic. If not possible, mitigate through selecting elastic where the latex material is enclosed thereby unlikely to come into contact with skin, and clearly label the product stating that the elastic contains latex. | Data sheet Product Labels | 2020-01-05 | 5 | 1 | 5 | No further risk reduction practicable | Yes | Severe allergic reactions to latex are extremely rare. The likelihood of infection of any member of staff through not wearing a visor is very high.
 |  |  |  |  | 0 |  |  |  |  |  |  | 0
 |  |  |  |  | 0 |  |  |  |  |  |  | 0
 |  |  |  |  | 0 |  |  |  |  |  |  | 0
 |  |  |  |  | 0 |  |  |  |  |  |  | 0
 |  |  |  |  | 0 |  |  |  |  |  |  | 0
 |  |  |  |  | 0 |  |  |  |  |  |  | 0
 |  |  |  |  | 0 |  |  |  |  |  |  | 0
 |  |  |  |  | 0 |  |  |  |  |  |  | 0
 |  |  |  |  | 0 |  |  |  |  |  |  | 0
 |  |  |  |  | 0 |  |  |  |  |  |  | 0
 |  |  |  |  | 0 |  |  |  |  |  |  | 0
 |  |  |  |  | 0 |  |  |  |  |  |  | 0
 |  |  |  |  | 0 |  |  |  |  |  |  | 0
 |  |  |  |  | 0 |  |  |  |  |  |  | 0
 |  |  |  |  | 0 |  |  |  |  |  |  | 0
 |  |  |  |  | 0 |  |  |  |  |  |  | 0
 |  |  |  |  | 0 |  |  |  |  |  |  | 0
 |  |  |  |  | 0 |  |  |  |  |  |  | 0
 |  |  |  |  | 0 |  |  |  |  |  |  | 0
 |  |  |  |  | 0 |  |  |  |  |  |  | 0
 |  |  |  |  | 0 |  |  |  |  |  |  | 0
 |  |  |  |  | 0 |  |  |  |  |  |  | 0
 |  |  |  |  | 0 |  |  |  |  |  |  | 0
 |  |  |  |  | 0 |  |  |  |  |  |  | 0
 |  |  |  |  | 0 |  |  |  |  |  |  | 0
 |  |  |  |  | 0 |  |  |  |  |  |  | 0
 |  |  |  |  | 0 |  |  |  |  |  |  | 0
 |  |  |  |  | 0 |  |  |  |  |  |  | 0
 |  |  |  |  | 0 |  |  |  |  |  |  | 0
 |  |  |  |  | 0 |  |  |  |  |  |  | 0
 |  |  |  |  | 0 |  |  |  |  |  |  | 0
 |  |  |  |  | 0 |  |  |  |  |  |  | 0
 |  |  |  |  | 0 |  |  |  |  |  |  | 0
 |  |  |  |  | 0 |  |  |  |  |  |  | 0
 |  |  |  |  | 0 |  |  |  |  |  |  | 0
 |  |  |  |  | 0 |  |  |  |  |  |  | 0
 |  |  |  |  | 0 |  |  |  |  |  |  | 0
 |  |  |  |  | 0 |  |  |  |  |  |  | 0
 |  |  |  |  | 0 |  |  |  |  |  |  | 0
 |  |  |  |  | 0 |  |  |  |  |  |  | 0
 |  |  |  |  | 0 |  |  |  |  |  |  | 0
 |  |  |  |  | 0 |  |  |  |  |  |  | 0
 |  |  |  |  | 0 |  |  |  |  |  |  | 0
 |  |  |  |  | 0 |  |  |  |  |  |  | 0
 |  |  |  |  | 0 |  |  |  |  |  |  | 0
 |  |  |  |  | 0 |  |  |  |  |  |  | 0
 |  |  |  |  | 0 |  |  |  |  |  |  | 0
 |  |  |  |  | 0 |  |  |  |  |  |  | 0
 |  |  |  |  | 0 |  |  |  |  |  |  | 0
 |  |  |  |  | 0 |  |  |  |  |  |  | 0
 |  |  |  |  | 0 |  |  |  |  |  |  | 0
 |  |  |  |  | 0 |  |  |  |  |  |  | 0
 |  |  |  |  | 0 |  |  |  |  |  |  | 0
 |  |  |  |  | 0 |  |  |  |  |  |  | 0
 |  |  |  |  | 0 |  |  |  |  |  |  | 0
 |  |  |  |  | 0 |  |  |  |  |  |  | 0
 |  |  |  |  | 0 |  |  |  |  |  |  | 0
 |  |  |  |  | 0 |  |  |  |  |  |  | 0
 |  |  |  |  | 0 |  |  |  |  |  |  | 0
 |  |  |  |  | 0 |  |  |  |  |  |  | 0
 |  |  |  |  | 0 |  |  |  |  |  |  | 0
 |  |  |  |  | 0 |  |  |  |  |  |  | 0
 |  |  |  |  | 0 |  |  |  |  |  |  | 0
 |  |  |  |  | 0 |  |  |  |  |  |  | 0
 |  |  |  |  | 0 |  |  |  |  |  |  | 0
 |  |  |  |  | 0 |  |  |  |  |  |  | 0
 |  |  |  |  | 0 |  |  |  |  |  |  | 0
 |  |  |  |  | 0 |  |  |  |  |  |  | 0
 |  |  |  |  | 0 |  |  |  |  |  |  | 0
 |  |  |  |  | 0 |  |  |  |  |  |  | 0
 |  |  |  |  | 0 |  |  |  |  |  |  | 0
 |  |  |  |  | 0 |  |  |  |  |  |  | 0
 |  |  |  |  | 0 |  |  |  |  |  |  | 0
 |  |  |  |  | 0 |  |  |  |  |  |  | 0
 |  |  |  |  | 0 |  |  |  |  |  |  | 0
 |  |  |  |  | 0 |  |  |  |  |  |  | 0
 |  |  |  |  | 0 |  |  |  |  |  |  | 0
 |  |  |  |  | 0 |  |  |  |  |  |  | 0
 |  |  |  |  | 0 |  |  |  |  |  |  | 0
 |  |  |  |  | 0 |  |  |  |  |  |  | 0
 |  |  |  |  | 0 |  |  |  |  |  |  | 0
 |  |  |  |  | 0 |  |  |  |  |  |  | 0
 |  |  |  |  | 0 |  |  |  |  |  |  | 0
 |  |  |  |  | 0 |  |  |  |  |  |  | 0
 |  |  |  |  | 0 |  |  |  |  |  |  | 0
 |  |  |  |  | 0 |  |  |  |  |  |  | 0
 |  |  |  |  | 0 |  |  |  |  |  |  | 0
 |  |  |  |  | 0 |  |  |  |  |  |  | 0
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

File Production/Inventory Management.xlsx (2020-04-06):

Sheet: BoM
Stock unit = 1 Carton, comprising |  | 24 | Shields
 | Item | Current spec | Quantity / units | Shield | Carton | Backflush / Carton
 | Visor | 200um PET |  | 1 |  | 24
 | Elastic | White elastic | 0.345 | 1 |  | 24
 | Foam | White medical grade | 28x230 | 1 |  | 24
 | Staple | 26/6 | 1 | 2 |  | 48
 | Product Label | Avery L4731 | 1 | 2 |  | 48
 | Bag | 300x400 PP | 1 | 1 |  | 24
 | Carton | Suttons 300x450x350 | 1 |  | 1 | 1
 | Carton label | Q connect 8up 67.5x99 | 1 |  | 1 | 1
 | Tape | Brown packing 3", 33m | 1.1 |  | 1 | 1.1

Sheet: TX
Date Ordered mm/dd | Our Order Reference | Due Date mm/dd | ACTUAL Date Delivered mm/dd | We bought for | Form | QTY | Shields per | Total shields
2020-01-04 |  | 2020-03-31 | 2020-04-02 | Visor | Roll | 100 | 2 | 200
2020-01-04 |  | 2020-03-31 | 2020-04-02 | Visor | Sheet | 100 | 2 | 200
 |  |  |  | Foam | Sheet | 1 | 270 | 270
 |  |  |  | Elastic | Roll |  |  | 0
 |  |  |  | Staple | Box | 2000 | 0.5 | 1000
 |  |  |  | Product Label | Sheet | 4725 | 0.5 | 2362.5
 |  |  |  | Bag |  |  | 1 | 0
 |  |  |  | Carton |  |  | 24 | 0
 |  |  |  | Carton label |  |  | 24 | 0
 |  |  |  | Tape |  |  | 24 | 0
 |  |  |  | Elastic |  |  |  | 0

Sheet: SUMMARY
2020-04-04 |  | Total Received | Total backflushed | On Hand Stock Predicted | OHS LAST COUNT | Forward Order | FO Outstanding
 | Visor | 400 | 768 | -368 | 222 | 0 | 0
 | Elastic | 0 | 768 | -768 | 13 | 0 | 0
 | Foam | 0 | 768 | -768 |  | 270 | 0
 | Staple | 0 | 1536 | -1536 |  | 1000 | 0
 | Product Label | 0 | 1536 | -1536 |  | 2362.5 | 0
 | Bag | 0 | 768 | -768 |  | 0 | 0
 | Carton | 0 | 32 | -32 |  | 0 | 0
 | Carton label | 0 | 32 | -32 |  | 0 | 0
 | Tape | 0 | 35.2 | -35.2 |  | 0 | 0
 |  | 0 | #N/A | #N/A |  | 0 | 0
 |  | 0 | #N/A | #N/A |  | 0 | 0

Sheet: Runrate
 |  | ACTIVITY DATE | 2020-04-02 | 2020-04-03 | 2020-04-04 | 2020-04-05 | 2020-04-06
How many you made | 1. Production Backflushed | 32 | 32
What physical stock left at end of day | 2. Inventory | OHS | LAST COUNT
 | Visor | 222 | 222
 | Elastic | 13 | 13
 | Foam
 | Staple
 | Product Label
 | Bag
 | Carton
 | Carton label
 | Tape

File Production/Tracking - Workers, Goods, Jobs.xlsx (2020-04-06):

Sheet: Workers
Registered Date | Name | Makespace member? | Mobile | Email | Member number
date/time | name | y/n | Mobile | Email

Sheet: Signins
Time in | Name | Symptoms | Contact with symptomatic person? | In same household as other worker? | Household detail | Notes
time in (dd/mm/yy hh:mm) | name | y/n | y/n | y/n

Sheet: Signouts
Time out | Name
dd/mm/yyyy hh:mm | name

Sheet: Suppliers
Material | Supplier | Address | Phone | VAT REG :
Foam | eFoam | Unit 20 Barton Industrial Park, Etruria Way, Bilston, West Midlands, WV14 7LH, UNITED KINGDOM | 0800 0439990 | 748 2373 13

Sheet: Goods In
Date | Carrier | Material | Supplier | Order number | Person receiving | Storage area | Contents Checked by | Their Lot number | Notes
dd/mm/yyyy | Amazon, DHL, FEDex .. | e.g. foam | e.g. e-foam

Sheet: Goods Out
Date | Batch | Person Shipping | Destination | Person Receiveing | Carrier | Order number | Notes
dd/mm/yyyy | MS- |  |  |  | Amazon, DHL, FEDex ..

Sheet: JobLog
Lot number | Workstation | Worker | Job Card Generation Time | Lots Consumed | Box Number | Comment | Additional Worker 1 | Additional Worker 2 | Completion Time | Lot Consumed Time | Retired by
0 | GoodsIn |  | 2020-03-30 15:41 | ELASTIC-2020330-1 |  |  |  |  |  | y
1 | GoodsIn |  | 2020-03-30 15:41 | PET05-20200330-1 |  |  |  |  |  | y
2 | GoodsIn |  | 2020-03-30 15:41 | PET07-20200330-1 |  |  |  |  |  | y
3 | CutElastic |  | 2020-03-30 15:46 | 0 |  |  |  |  |  | y
4 | LaserCutShield |  | 2020-03-30 15:50 | 1 |  |  |  |  |  | y
5 | LaserCutShield |  | 2020-03-30 15:50 | 2 |  |  |  |  |  | y
6 | LaserCutShield |  | 2020-03-30 15:51 | 1 |  |  |  |  |  | y
7 | GoodsIn |  | 2020-03-30 16:38 | FOAM-2020330-1 |  |  |  |  |  | y
8 | GoodsIn |  | 2020-03-30 16:45 | BOX-20200330-1 |  |  |  |  |  | 2020-04-04 18:46
9 | CutFoam |  | 2020-03-30 16:46 | 7 |  |  |  |  |  | y
10 | StickFoamToShield |  | 2020-03-30 16:55 | 4;9 |  |  |  |  |  | y
11 | CutFoam |  | 2020-03-30 16:57 | 7 |  |  |  |  |  | y
12 | CutFoam |  | 2020-03-30 17:30 | 7 |  |  |  |  |  | y
13 | Void |  | 2020-03-30 17:32 | 7 |  |  |  |  |  | y
14 | CutFoam |  | 2020-03-30 17:33 | 7 |  |  |  |  |  | y
15 | StapleElasticToShield |  | 2020-03-30 17:54 | 10;3 |  |  |  |  |  | y
16 | StickFoamToShield |  | 2020-03-30 18:31 | 6;11 |  |  |  |  |  | y
17 | CutFoam |  | 2020-03-30 18:38 | 7 |  |  |  |  |  | y
18 | CutFoam |  | 2020-03-30 18:38 | 7 |  |  |  |  |  | 2020-04-01 18:25
19 | GoodsIn |  | 2020-03-30 18:59 | PET02-20200330-1
20 | CutFoam |  | 2020-03-30 19:04 | 7 |  |  |  |  |  | y
21 | CutElastic |  | 2020-03-30 19:05 | 0 |  |  |  |  |  | y
22 | QualityControlPass |  | 2020-03-30 19:14 | 15;8 |  |  |  |  |  | y
23 | LaserCutShield |  | 2020-03-30 19:14 | 19 |  |  |  |  |  | y
24 | Boxing |  | 2020-03-30 19:23 | 22 | 1
25 | CutElastic |  | 2020-03-30 19:24 | 0 |  |  |  |  |  | y
26 | LaserCutShield |  | 2020-03-31 10:22 | 19 |  |  |  |  |  | y
27 | Void |  | 2020-03-31 10:41 | 7 |  |  |  |  |  | y
28 | CutElastic |  | 2020-03-31 10:41 | 7 |  |  |  |  |  | y
29 | CutElastic |  | 2020-03-31 10:46 | 7 |  |  |  |  |  | y
30 | StickFoamToShield |  | 2020-03-31 10:49 | 23;14 |  |  |  |  |  | y
31 | Void |  | 2020-03-31 10:54 | 7 |  |  |  |  |  | y
32 | CutFoam |  | 2020-03-31 10:54 | 7 |  |  |  |  |  | y
33 | CutFoam |  | 2020-03-31 10:56 | 7 |  |  |  |  |  | y
34 | CutFoam |  | 2020-03-31 11:01 | 7 |  |  |  |  |  | y
35 | GoodsIn |  | 2020-03-31 11:24 | PET02-20200331-1
36 | LaserCutShield |  | 2020-03-31 11:25 | 35 |  |  |  |  |  | y
37 | StickFoamToShield |  | 2020-03-31 11:36 | 26;34 |  |  |  |  |  | y
38 | StickFoamToShield |  | 2020-03-31 11:52 | 12;5 |  |  |  |  |  | y
38 | StickFoamToShield |  | 2020-03-31 11:52 | 12;5 |  |  |  |  |  | y
39 | CutFoam |  | 2020-03-31 11:57 | 7 |  |  |  |  |  | y
40 | Void |  | 2020-03-31 12:06 | 7 |  |  |  |  |  | y
41 | CutFoam |  | 2020-03-31 12:06 | 7 |  |  |  |  |  | y
42 | StapleElasticToShield |  | 2020-03-31 12:15 | 16;18 |  |  |  |  |  | y
43 | LaserCutShield |  | 2020-03-31 12:15 | 19 |  |  |  |  |  | y
44 | LaserCutShield |  | 2020-03-31 12:17 | 19 |  |  |  |  |  | y
45 | StickFoamToShield |  | 2020-03-31 12:29 | 26;28 |  |  |  |  |  | y
46 | Void |  | 2020-03-31 12:45 | 45;21 |  |  |  |  |  | y
47 | StapleElasticToShield |  | 2020-03-31 12:45 | 45;21 |  |  |  |  |  | y
48 | StickFoamToShield |  | 2020-03-31 12:48 | 43;29 |  |  |  |  |  | y
49 | QualityControlPass |  | 2020-03-31 12:49 | 42;47;8 |  |  |  |  |  | y
50 | LaserCutShield |  | 2020-03-31 12:51 | 35 |  |  |  |  |  | y
51 | LaserCutShield |  | 2020-03-31 13:19 | 35 |  |  |  |  |  | y
52 | StapleElasticToShield |  | 2020-03-31 13:26 | 48;42 |  |  |  |  |  | y
53 | StickFoamToShield |  | 2020-03-31 13:31 | 36;41 |  |  |  |  |  | y
54 | StickFoamToShield |  | 2020-03-31 13:31 | 36;41 |  |  |  |  |  | y
55 | LaserCutShield |  | 2020-03-31 13:32 | 19 |  |  |  |  |  | y
56 | LaserCutShield |  | 2020-03-31 13:32 | 19 |  |  |  |  |  | y
57 | LaserCutShield |  | 2020-03-31 13:36 | 35 |  |  |  |  |  | y
58 | StickFoamToShield |  | 2020-03-31 14:00 | 44;39 |  |  |  |  |  | y
58 | StickFoamToShield |  | 2020-03-31 14:00 | 44;39 |  |  |  |  |  | y
59 | LaserCutShield |  | 2020-03-31 14:01 | 35 |  |  |  |  |  | y
60 | LaserCutShield |  | 2020-03-31 14:34 | 35 |  |  |  |  |  | y
61 | QualityControlFail |  | 2020-03-31 14:37 | 42 |  |  |  |  |  | y
62 | StickFoamToShield |  | 2020-03-31 14:41 | 50;32 |  |  |  |  |  | y
63 | StickFoamToShield |  | 2020-03-31 14:45 | 51;33 |  |  |  |  |  | y
64 | GoodsIn |  | 2020-03-31 14:50 | ELASTIC-20200331-1
65 | CutElastic |  | 2020-03-31 14:56 | 64 |  |  |  |  |  | y
66 | CutFoam |  | 2020-03-31 15:01 | 7 |  |  |  |  |  | y
67 | CutFoam |  | 2020-03-31 15:20 | 7 |  |  |  |  |  | y
68 | StapleElasticToShield |  | 2020-03-31 15:21 | 63;65 |  |  |  |  |  | y
69 | LaserCutShield |  | 2020-03-31 15:22 | 19 |  |  |  |  |  | y
70 | CutElastic |  | 2020-03-31 15:23 | 64 |  |  |  |  |  | y
71 | LaserCutShield |  | 2020-03-31 15:28 | 35 |  |  |  |  |  | y
72 | LaserCutShield |  | 2020-03-31 15:38 | 19 |  |  |  |  |  | y
73 | StapleElasticToShield |  | 2020-03-31 15:40 | 62;65 |  |  |  |  |  | y
74 | StickFoamToShield |  | 2020-03-31 15:42 | 56;67 |  |  |  |  |  | y
75 | StickFoamToShield |  | 2020-03-31 15:44 | 57;66 |  |  |  |  |  | y
76 | CutFoam |  | 2020-03-31 15:48 | 7 |  |  |  |  |  | y
77 | StapleElasticToShield |  | 2020-03-31 15:52 | 74;70 |  |  |  |  |  | y
78 | GoodsIn |  | 2020-03-31 15:57 | SHIPPINGBAGS-20200331-1
79 | LaserCutShield |  | 2020-03-31 15:59 | 19 |  |  |  |  |  | 2020-04-01 18:34
80 | CutElastic |  | 2020-03-31 16:10 | 64 |  |  |  |  |  | y
81 | StickFoamToShield |  | 2020-03-31 16:20 | 60;76 |  |  |  |  |  | y
82 | CutFoam |  | 2020-03-31 16:23 | 7 |  |  |  |  |  | y
83 | LaserCutShield |  | 2020-03-31 16:23 | 19 |  |  |  |  |  | y
84 | QualityControlPass |  | 2020-03-31 16:28 | 47;8;78 |  |  |  |  |  | y
85 | Boxing |  | 2020-03-31 16:35 | 84 | 3
86 | StapleElasticToShield |  | 2020-03-31 16:39 | 58;80 |  |  |  |  |  | y
87 | CutElastic |  | 2020-03-31 16:39 | 64 |  |  |  |  |  | y
88 | StickFoamToShield |  | 2020-03-31 16:43 | 59;82 |  |  |  |  |  | y
89 | LaserCutShield |  | 2020-03-31 16:44 | 19 |  |  |  |  |  | y
90 | LaserCutShield |  | 2020-03-31 16:44 | 19 |  |  |  |  |  | y
91 | QualityControlPass |  | 2020-03-31 16:58 | 68;8;78 |  |  |  |  |  | y
92 | StapleElasticToShield |  | 2020-03-31 17:07 | 88;87 |  |  |  |  |  | y
93 | StapleElasticToShield |  | 2020-03-31 17:28 | 54;87 |  |  |  |  |  | y
94 | StapleElasticToShield |  | 2020-03-31 17:53 | 58;80 |  |  |  |  |  | y
95 | Void |  | 2020-03-31 17:55 | 7 |  |  |  |  |  | y
96 | CutFoam |  | 2020-03-31 17:56 | 7 |  |  |  |  |  | y
97 | QualityControlPass |  | 2020-03-31 18:02 | 77;42;8;78 |  |  |  |  |  | y
98 | QualityControlFail |  | 2020-03-31 18:05 | 77 |  |  |  |  |  | y
99 | StapleElasticToShield |  | 2020-03-31 18:21 | 30;80 |  |  |  |  |  | y
100 | StickFoamToShield |  | 2020-03-31 18:41 | 83;96 |  |  |  |  |  | y
101 | CutFoam |  | 2020-03-31 18:44 | 7 |  |  |  |  |  | y
102 | Boxing |  | 2020-03-31 18:47 | 97 | 5
103 | LaserCutShield |  | 2020-03-31 18:48 | 35 |  |  |  |  |  | y
104 | CutFoam |  | 2020-03-31 18:48 | 7 |  |  |  |  |  | y
105 | StickFoamToShield |  | 2020-03-31 18:49 | 69;96 |  |  |  |  |  | y
106 | StapleElasticToShield |  | 2020-03-31 19:01 | 81;80
106 | StapleElasticToShield |  | 2020-03-31 19:01 | 81;80 |  |  |  |  |  | 2020-04-02 15:23
107 | QualityControlPass |  | 2020-03-31 19:14 | 93;42;8;78 |  |  |  |  |  | y
108 | Boxing |  | 2020-03-31 19:16 | 107 | 6
109 | StickFoamToShield |  | 2020-03-31 19:17 | 71;104 |  |  |  |  |  | y
110 | CutFoam |  | 2020-03-31 19:21 | 7 |  |  |  |  |  | y
111 | CutFoam |  | 2020-03-31 19:23 | 7 |  |  |  |  |  | y
112 | StickFoamToShield |  | 2020-03-31 19:23 | 90;110 |  |  |  |  |  | y
113 | CutFoam |  | 2020-03-31 19:32 | 7 |  |  |  |  |  | y
114 | StapleElasticToShield |  | 2020-03-31 19:33 | 100;80 |  |  |  |  |  | 2020-04-01 20:30
115 | StickFoamToShield |  | 2020-03-31 19:43 | 79;113 |  |  |  |  |  | y
116 | CutFoam |  | 2020-03-31 19:53 | 7 |  |  |  |  |  | y
117 | CutElastic |  | 2020-03-31 19:54 | 64 |  |  |  |  |  | y
118 | StickFoamToShield |  | 2020-03-31 19:56 | 103;111 |  |  |  |  |  | y
119 | StickFoamToShield |  | 2020-03-31 20:02 | 72;116 |  |  |  |  |  | y
120 | Boxing |  | 2020-03-31 20:22 | 91 | 4
121 | QualityControlPass |  | 2020-03-31 20:29 | 92;8;78 |  |  |  |  |  | y
122 | Boxing |  | 2020-03-31 20:35 | 121 | 8
123 | QualityControlPass |  | 2020-03-31 20:54 | 99;8;78 | 8 |  |  |  |  | y
124 | QualityControlFail |  | 2020-03-31 20:57 | 99 |  |  |  |  |  | y
125 | Boxing |  | 2020-03-31 20:57 | 123 | 7
126 | CutFoam |  | 2020-04-01 10:00 | 7 |  |  |  |  |  | y
127 | LaserCutShield |  | 2020-04-01 10:03 | 19 |  |  |  |  |  | y
128 | LaserCutShield |  | 2020-04-01 10:06 | 19 |  |  |  |  |  | y
129 | CutFoam |  | 2020-04-01 10:14 | 7 |  |  |  |  |  | y
130 | CutFoam |  | 2020-04-01 10:21 | 7 |  |  |  |  |  | y
131 | StickFoamToShield |  | 2020-04-01 10:23 | 127;126 |  |  |  |  |  | y
132 | StapleElasticToShield |  | 2020-04-01 10:34 | 119;117 |  |  |  |  |  | y
133 | LaserCutShield |  | 2020-04-01 10:51 | 19 |  |  |  |  |  | y
134 | Void |  | 2020-04-01 10:53 | 19 |  |  |  |  |  | y
135 | LaserCutShield |  | 2020-04-01 10:53 | 19 |  |  |  |  |  | y
136 | StickFoamToShield |  | 2020-04-01 11:00 | 128;130 |  |  |  |  |  | y
137 | CutFoam |  | 2020-04-01 11:10 | 7 |  |  |  |  |  | y
138 | CutElastic |  | 2020-04-01 11:23 | 64 |  |  |  |  |  | y
139 | StapleElasticToShield |  | 2020-04-01 11:25 | 118;138 |  |  |  |  |  | y
140 | StickFoamToShield |  | 2020-04-01 11:26 | 133;137 |  |  |  |  |  | y
141 | CutElastic |  | 2020-04-01 11:28 | 64 |  |  |  |  |  | y
142 | Void |  | 2020-04-01 11:48 | 135;129 |  |  |  |  |  | y
143 | StickFoamToShield |  | 2020-04-01 11:48 | 135;129 |  |  |  |  |  | y
144 | CutElastic |  | 2020-04-01 11:50 | 64 |  |  |  |  |  | y
145 | StapleElasticToShield |  | 2020-04-01 11:51 | 115;141 |  |  |  |  |  | y
146 | CutFoam |  | 2020-04-01 11:52 | 7 |  |  |  |  |  | y
147 | Void |  | 2020-04-01 12:01 | 19 |  |  |  |  |  | y
148 | LaserCutShield |  | 2020-04-01 12:01 | 19 |  |  |  |  |  | y
149 | LaserCutShield |  | 2020-04-01 12:02 | 19 |  |  |  |  |  | y
150 | StapleElasticToShield |  | 2020-04-01 12:03 | 112;144 |  |  |  |  |  | 2020-04-01 20:56
151 | QualityControlPass |  | 2020-04-01 12:05 | 94;8;78 |  |  |  |  |  | y
152 | StickFoamToShield |  | 2020-04-01 12:08 | 148;146 |  |  |  |  |  | y
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

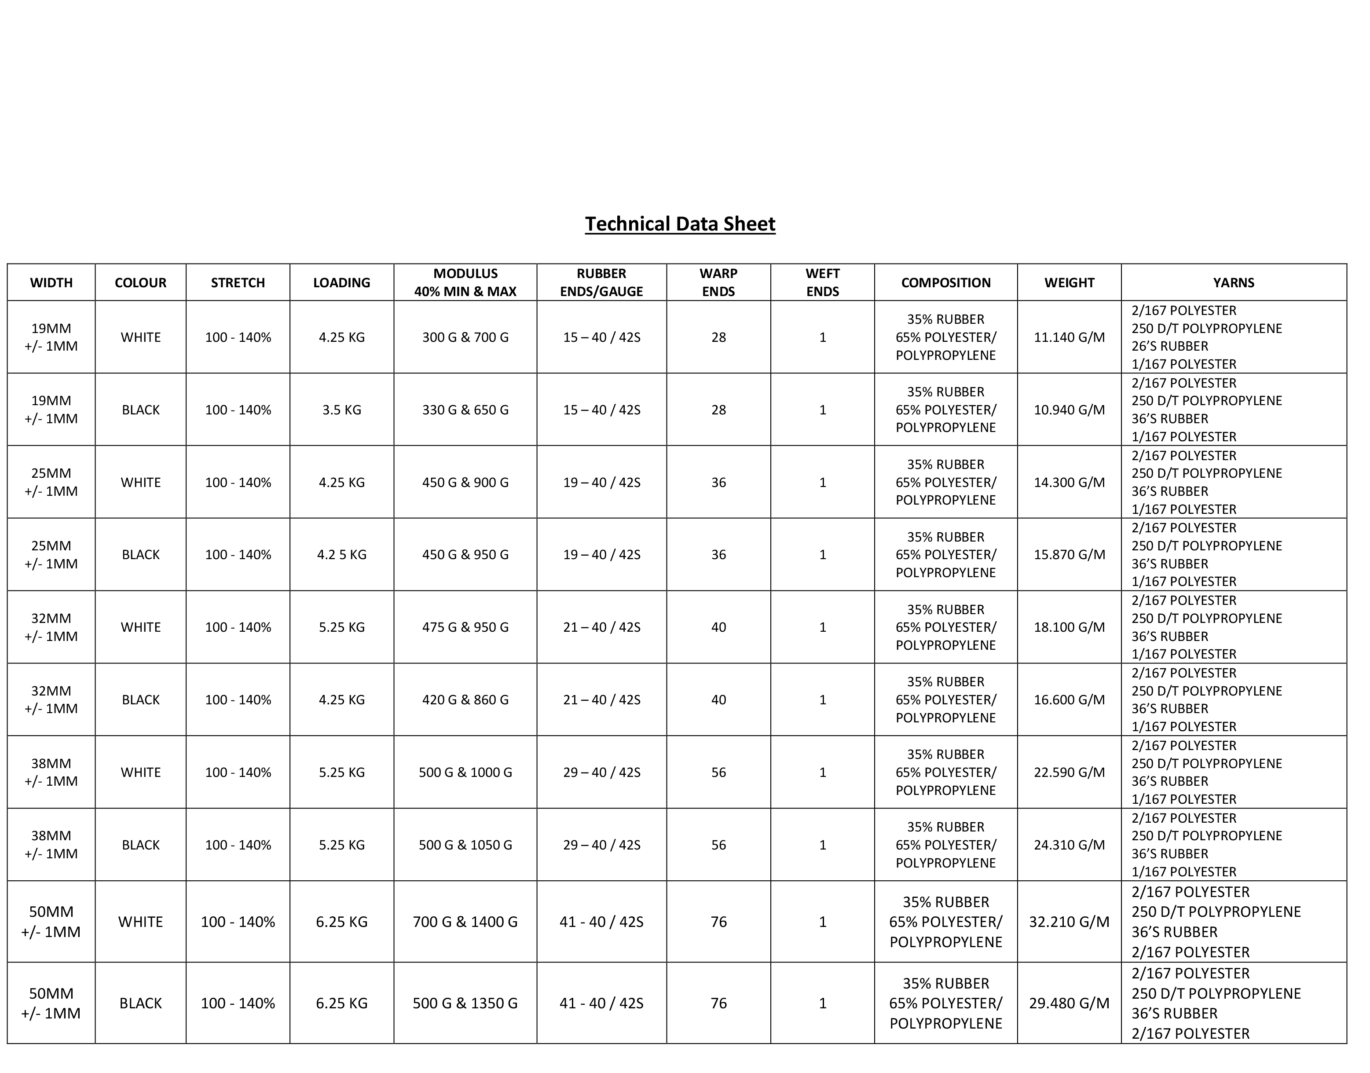
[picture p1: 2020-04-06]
Materials/Datasheet - W03 Woven Elastic.jpg

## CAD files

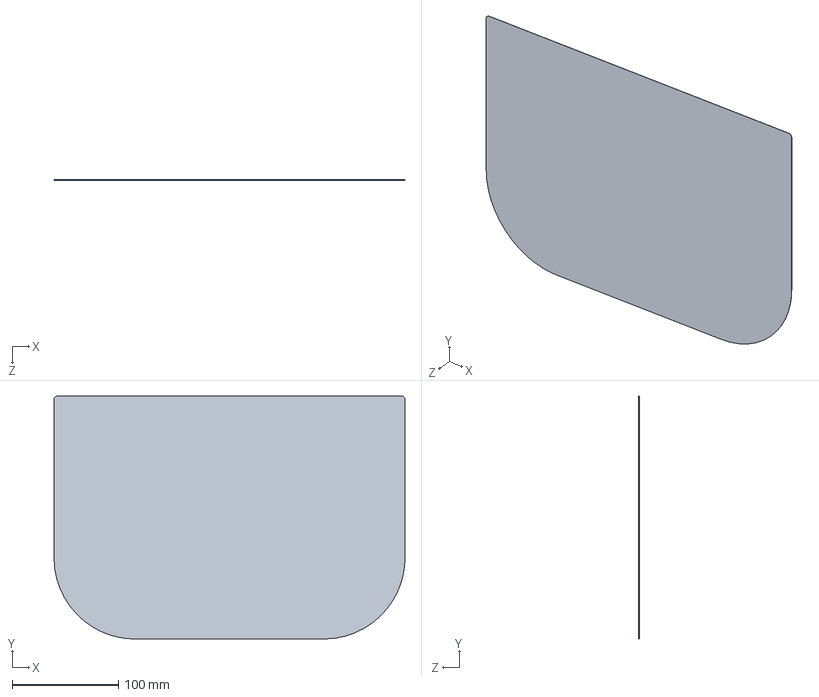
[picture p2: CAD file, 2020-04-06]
Design Files/visor PET.SLDPRT
330.2 x 228.6 x 0.2 mm

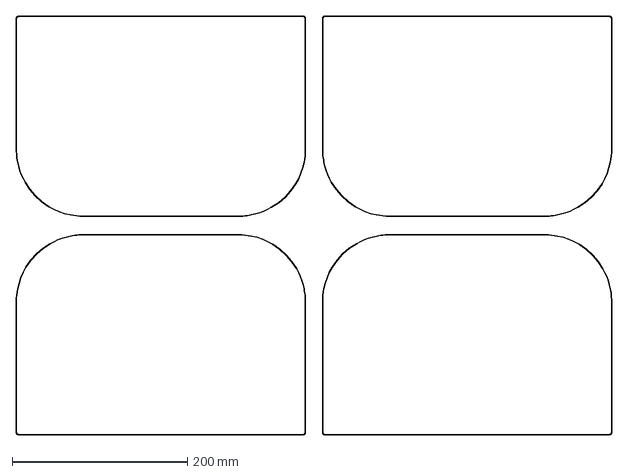
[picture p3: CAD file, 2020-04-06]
Design Files/visor PET nested.DXF
680.2 x 478.6 mm

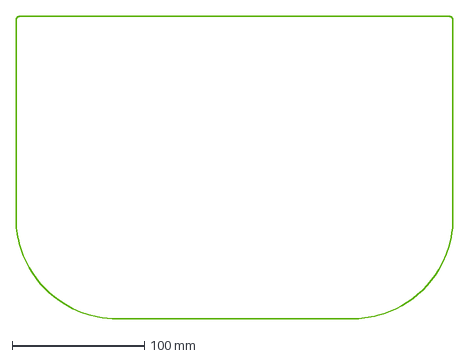
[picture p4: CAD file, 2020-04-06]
Design Files/Open-Source-Face-Shield-Polyline.dxf
330.2 x 228.6 mm

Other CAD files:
Design Files/visor PET.SLDDRW

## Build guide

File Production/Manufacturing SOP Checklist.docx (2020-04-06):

# Manufacturing SOP Checklist

# Scope & Purpose

To be used by the Supervisor to check off that all activities have been done by the Technician correctly and in the correct order.

# 1. Entry to Makespace

- Outdoor clothing removed and stored in the ‘Dirty Goods In’ area, away from work tables
- Sign in
- “Dirty goods in” “Prep area” and “Production Area” are clearly designated (e.g. by tape) and understood by all personnel

TO OUTSIDE

CORRIDOR

KEY

Door

Work Table

Laser Cutter

Laser Cutter Computer

Other Equipment

Sink

FINISHED GOODS OUT

PREP AREA

CLEAN GOODS IN

CUTTING & ASSEMBLY

PACKAGING

CORRIDOR

DIRTY GOODS IN

LOGGING GOODS IN

STORAGE - LOGGED GOODS

UNPACKING/ CLEANING GOODS IN

STORAGE - NEW GOODS

Movement of personnel

# 2. Preparation of work areas

- Prepare cleaning materials:
  - Regular water, detergent & cloths
  - EPA approved disinfectant solution & cloth
- Enter “Prep Area”:
  - Wash hands for 20s
  - Don surgical mask
  - Don gloves
- Clean “Production Area”:
  - Clean floor and work tables with regular cleaning materials
  - Disinfect work tables
  - Prep each tool/piece of equipment by wiping it with a cloth wetted with disinfectant , and placing it in the appropriate location for use
  - Check off each piece of equipment:
    - Laser Cutters wiped down - cover, and sides/edges that may be touched when cover is open
    - Laser Cutter bed -
    - Computer keyboard wiped down
    - Steel bars (weights) next to laser cutter (cleaned)
    - “Assembly Area” contains:
      - Cutting matt (cleaned)
      - Stanley knife (cleaned)
      - 1m metal ruler (cleaned)
      - Scissors (cleaned)
      - Stapler (cleaned)
      - Staples QUANTITY
      - Cardboard box labelled “Elastic Strips WIP” lined with bin liner. Bin liner labelled with date & initials of Technician in format “ MS-yy/mm/dd-’Initials’ “
      - Cardboard box labelled “Foam Strips WIP” lined with bin liner. Bin liner labelled with date & initials of Technician in format “ MS-yy/mm/dd-’Initials’ “
    - “Packaging Area”
      - Label maker (cleaned)
      - Individual product labels QUANTITY
      - Instructions For Use QUANTITY
      - Shipping labels QUANTITY
      - Plastic bags for packing QUANTITY
      - Stack of flat pack boxes QUANTITY
    - Bin for waste material (cleaned)

TO OUTSIDE

CORRIDOR

KEY

Door

Work Table

Laser Cutter

Laser Cutter Computer

Other Equipment

Sink

FINISHED GOODS OUT

PREP AREA

CLEAN GOODS IN

CUTTING & ASSEMBLY

PACKAGING

CORRIDOR

DIRTY GOODS IN

LOGGING GOODS IN

STORAGE - LOGGED GOODS

UNPACKING/ CLEANING GOODS IN

STORAGE - NEW GOODS

Flat-pack boxes

Plastic bags

Product Labels

Shipping Labels

Label Maker

WIP - Elastic

Cutting mat

Knife

Scissors

1m ruler

WIP - Foam

Visor Jig

Stapler

Staples

BIN

Weights

- Set up label maker to print labels with today’s date and the initials of the Technician and Supervisor
- Enter “Dirty Goods In”:
  - Clean floor and work tables with regular cleaning materials
  - Disinfect work tables
  - Doff gloves (bin)
  - Doff surgical mask (bin for washing)

# 3. Logging incoming goods

*May be excluded if proceeding straight to step 4

- Unpackaged goods should be left in their boxes in the area marked “Storage - New Goods”
- Before handling goods:
  - Enter “Prep Area”
  - Wash hands for 20s
  - Don surgical mask
  - Don gloves
- Move goods to work table “Logging goods in”
  - Open box, but do not remove any plastic wrapping
  - Log contents in ‘Goods In/Out Log”
  - Repackage in box if necessary
- Place goods in “Storage - Logged Goods”
- *Doff gloves (bin)
- *Doff surgical mask (bin for washing)

# 4. Preparation of incoming goods

*May be excluded if proceeding straight from step 3

- *Before handling goods:
  - *Enter “Prep Area”
  - *Wash hands for 20s
  - *Don surgical mask
  - *Don gloves
- Move goods from “Storage - Logged Goods” to work table “Unpacking/cleaning goods in”
  - Open box and remove plastic wrapping
  - Log contents in ‘Goods In/Out Log”
  - Transfer items to “Clean Goods In”
- Check raw materials
- Doff gloves (bin)
- Doff surgical mask (bin for washing)

# 5. Production

- Enter “Prep Area”
  - Wash hands for 20s
  - Don surgical mask
  - Don gloves

# a. Preparation of Elastic & Foam

- Take elastic and foam raw material from “Clean Goods In” to “Cutting & Assembly”
- Cut elastic into 33 ± 1 cm strips and place in “Elastic Strips WIP”
- Cut foam into 23 ± 2 cm by 2.8 ± 0.5 cm strips and place in “Foam Strips WIP”. DO NOT remove adhesive material.

# b. Laser cutting visors

- Do not remove protective film
- Place material on laser cutter, weigh down the center of where each visor will be cut with steel blocks
- Laser Cutter settings: 20% power, 60mm/s for 60W laser
- Cut using the supplied .dxf file (visor PET nested.DXF)
- Place cut visors in “Cutting & Assembly”

# c. Assembly

- Peel back protective film on visor enough to attach foam and elastic (about 4cm from top of shield)
- Place in jig
- Remove adhesive from foam, use jig to stick foam centrally on top edge of shield
- Quality Control:
  - Reject foam pieces that are more than 2cm shorter than the foam positioning slot in the jig
  - Re-cut foam pieces that are too long or too wide
- Remove visor from jig
- Lay elastic parallel against top edge of visor
- Quality Control:
  - Reject elastic that is more than 1cm shorter than width of visor
- Add 2 staples approximately 0.5cm-1.5cm from side of visor to fasten the elastic to the plastic of the visor
- Place finished items in the “Packaging Area”

# d. Packaging

- Remove protective plastic from visor
- Quality Control:
  - Reject visors with scratches greater than 1cm in length in line of sight
  - Reject visors with defects on the outer edge that may scratch and damage skin
  - Reject visors with the foam/elastic attached to the bottom of the visor
  - Reject visors where the staples have closed improperly forming a hazard which could cause minor injury such as scratches to hand/face
  - Reject visors with less than 2 staples
- Place label on outside of visor, in upper right corner (so label is on the other side of the plastic to the foam, and does not impede vision)
- Place each visor in plastic bag
- Pack 24 bags into each box
- Label the box with shipping instructions
- Place box at edge of “Production Area” in “Goods Out Zone”
- Clear any debris/waste materials into the bin
- Leave “Production Area” through “Prep Area”
  - Doff gloves (bin)
  - Doff surgical mask (bin)

# 6. Goods Out

- Without entering “Production Area”, take boxes from “Goods Out Zone”
- Ship

# 7. Cleaning Up

- Without entering “Production Area”, remove and empty bin
- Leave bin outside “Production Area” to be cleaned and replaced at the start of the next day of production

# 8. Non-conformances

- If there is any non-conformance to this SOP (for example, entering the “Production Area” during production without PPE) the following actions should be taken:
  - Log the non-conformance in “Non-Conformance Log”
  - Label affected boxes of finished product with “Non-Conformance Label”
- These actions should also be taken if it is not possible to follow this SOP due to external constraints

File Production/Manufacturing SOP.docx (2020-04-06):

# Manufacturing SOP: Face Visor Assembly

Author: John Loveluck Version 21 April 2020

# 1. Purpose

To define:

- Process for assembling Delve Face Visors
- Precautions to prevent spread of COVID-19 by contamination of face visors during manufacture and distribution
- Means of recording implementation of processes and precautions.

# 2. Scope

Qualified staff/volunteers manufacturing the Addenbrooke’s approved design of DELVE face visor at Makespace, Mill Lane, Cambridge.

# 3. Responsibilities

All:

- To ensure Makespace facility remains a “safe zone”, free of virus as far as possible
- Not to enter the Makespace facility if you show any symptoms that could indicate COVID-19, or you have been in recent contact with anyone showing symptoms.
- Report any symptoms that arise within 5 days of working in the Makespace facility to cei@addenbrookes.nhs.uk

Supervisor:

- Ensure process is conducted according to SOP
- Document & report any non-conformances

Technician:

- Conduct cleaning, assembly, packaging as described
- Wear PPE as required.

# 4. Hygiene Precautions

## a. Entry to workspace & Designation of Areas

Preventing the virus entering the workspace area is a high priority.

- All personnel will first enter “Contamination not controlled” area
- On entry to this area, all personnel must remove outdoor clothing and store it in “Staff outer vestibule area”, NOT on the worktables
- All personnel must record time of entry and exit and sign a statement of general good health, stating duration of isolation and any potential opportunities for virus transmission - this will allow traceability in case of subsequent symptoms appearing
- Before entering the “Production Area”:
  - Use the “Prep Area” to wash hands thoroughly
  - Don PPE
- To transition back from the “Production Area” to “Dirty Goods In”
  - Use the “Prep Area” to doff PPE
- To enter or leave the “Contamination controlled”, you must observe the strict prohibition of the gangway.
- To protect operators, all workstations are disinfected daily
- All parts must be kept in a WIP box when they are not being directly worked on
- WIP boxes and parts must only be placed on the work surfaces labelled on the diagram
- The operator work stations mapped out (per the standardised work sheet below) have been positioned to allow a minimum of 2m clearance between operators to minimise operator cross-contamination risks.

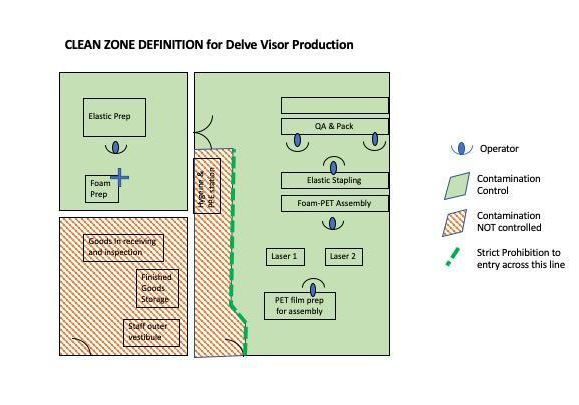
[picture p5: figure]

## b. Personal Protective Equipment (PPE)

The intent of PPE in this context is to prevent virus from assembly staff contaminating the visors in production. This is important, since asymptomatic individuals can spread the virus through touch and respiration.

The following are to be worn while handling all parts:

- Disposable gloves - replace if removed
- Face masks - paper or fabric masks should be sufficient for this risk. Vented masks should have the valve sealed closed so exhaling is also filtered

# 5. Equipment & Materials

## c. Equipment

- Laser cutters x 2
- Bandsaw
- Scissors
- Stapler
- Foam-to-visor assembly jig (3-off built, of which two commissioned)

## d. BoM Materials

- PET sheet or roll 0.20mm thick, sheet: 700 x 1000mm, makes 8 visors, Roll: 560mm wide, makes 2 visors per setup
- Latex free elastic, 25mm width, length 345mm
- Open cell Polyurethane foam sheet, 230mm x 28mm self-adhesive backing (1000 x 2000mm makes 320 visors with 10% waste)
- 26/6 Staples (2-off per shield)
- 2 labels: producer and batch details Avery L4731
- Clean PP bag 300mm x 400mm

## e. Packaging BoM materials

- Shipping Carton 300 x 400 x 350mm (Manufacturer: Sutton, source: Linx)
- 3” packing tape, Brown, 1000mm per Carton
- Labels 99mm x 67.5mm for carton ID and postponed use-after date (1-off per nominal case)
- Instructions for Use

## f. Consumables in production

- Permanent Pens labels for labelling WIP boxes
- A5 paper sheets for WIP Product labels
- 35L and 24L Really Useful Boxes for WIP
- Face masks, disposable or washable - sufficient for 1 mask per Technician per shift
- Disposable latex-free gloves - sufficient for 3 pairs per Technician per shift
- Cleaning cloths for all work surfaces
- Broom to remove production waste (eg dropped materials, release film from foam)
- Soap and hand gel for hand washing
- Paper towel for hand washing
- IPA solution for cleaning laser cut visors
- Approved cleaning solution
- Anti mist spray for cleaning inside visors
- Soft roll tissue for visor cleaning

# 6. Preparation of work areas and incoming goods

## 6.1 Cleaning work surfaces and equipment

Work surfaces and equipment must be cleaned before each work session using routine cleaning and disinfection procedures (e.g., use cleaners and water to pre-clean surfaces then apply an EPA-registered, hospital-grade disinfectant). https://www.epa.gov/pesticide-registration/list-n-disinfectants-use-against-sars-cov-2

The process for cleaning the space is as follows:

1. Place cleaning materials on ‘Dirty Goods In’ work table
2. Enter ‘Hygiene and PPE’ area via the marked out gangway only
3. Wash hands for 20 seconds, put on PPE in following order:
  a. Face mask
  b. Latex non-sterile gloves
4. Clean all work surfaces first with regular cleaning agents, followed by disinfectant
5. Clean all tools with appropriate cleaning wipes, then set them out in correct location as indication by the Production Layout Diagram
6. Return to the ‘Prep Area’ and:
  a. Remove gloves, place in bin
  b. Remove mask, place in bin

The area should be cleaned at the start of each work day, or if there is reason to believe the cleanliness of the space may have been compromised (e.g. entry of personnel not wearing correct PPE).

## 6.2 Goods receiving

Incoming goods should be logged and stored, but not completely unpackaged, in the “Incoming Goods” area.

Since viruses may remain viable for several days on surfaces, there is a risk that materials being brought into Makespace have been contaminated during distribution. Therefore, outer layers of packaging should be removed wherever possible before bringing materials into the production area.

If the product has not come in appropriate packaging, then it should be cleaned using a clean cloth and appropriate EPA approved disinfectant solution. In the case of elastic, it is appropriate to clean this on a hot wash in the washing machine.

Ensure that ‘clean’ goods are placed immediately onto a ‘clean’ table in the ‘Production Area’.

The receipt of goods is traced by the batch history Gsheet, which records the date stamp, operator identification and assigns a unique transaction serial number to the activity. This is transcribed onto an A5 card initiated by the operator.

# 7.Manufacturing process steps

The overall process is as in the diagram below.

Elastic straps and foam will be prepared in intermediate quantities before production. The Visors are then assembled in batches, target batch quantity is 24 (carton quantity).

A Batch Record is made electronically as work flows, and is mirrored by A5 travelers added at each step. Traceability will allow us to decide what action to take in the event of an individual displaying symptoms shortly after assembly.

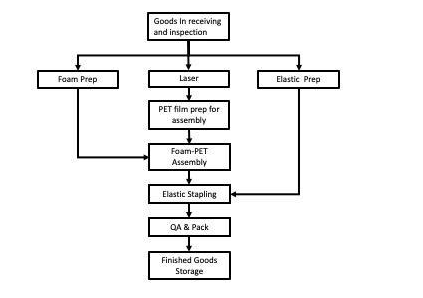
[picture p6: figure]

With the exception of Goods In Receiving and Inspection, Laser and Finished Goods Storage, there is a detailed single point lesson for each task describing the activity, quality outcomes and task-specific safety precautions.

Material should flow around the workspace as follows:

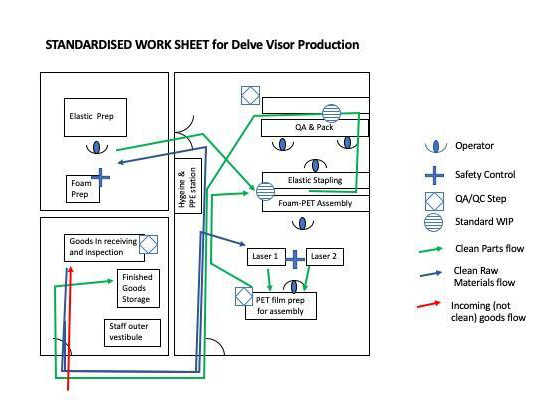
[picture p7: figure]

## QA and Pack

1. Quality Control:
  a. Reject visors with scratches greater than 1cm in length in line of sight
  b. Reject visors with the foam/elastic attached to the bottom of the visor
  c. Reject visors with less than 2 staples
  d. Reject if poor adhesion between visor and foam
  e. Reject if excessively bowed, indicating elastic is too short
  f. Any part of the PPE that is liable to come into contact with the user when the PPE is worn must be free of rough surfaces, sharp edges, sharp points and the like which could cause irritation or injuries:
    i. Reject visors with defects on the outer edge that may scratch and damage skin
    ii. Reject visors where the staples have closed improperly forming a hazard which could cause minor injury such as scratches to hand/face

# 8. Product Identification / Labelling

The visor is labelled directly with two labels, one to identify the producer and one to record its batch. They are:

Visor Product Label 1of2 v1.docx

Visor Product Label 2of2 v1.docx

The carton is identified with a single label, to be affixed to either of its minor vertical faces. This is:

Visor Carton Label 1of2.docx

If a risk of non-compliance to this SOP is identified in finished goods, a further label to quarantine and defer use of the visors before a defined date. This label should be immediately adjacent to the single carton label. This is

Visor Carton Label 2of2 v1.docx

The requirements of labelling, with examples, are in the additional document “Label Content”.

# 9.Supporting Documents

- Single Point Lesson for Visor Mfr v1.pptx

# 10.Change History

Version | Changes since previous version | Date / approver
1 | Not applicable, first issue | 30 March 2020 / Abi Bush
2 | Finalisation of manufacturing process steps and packaging specification | 01 April 2020 / Nick Scott

# Face Visor Batch Record

To be completed for each batch of Visor assemblies

Batch Number (FV-20mmdd-n) | Date started
FV-20

Material | | Initials | Comments
PET batch
Elastic Strap Batch
Brow Foam Batch

Process Step | Initials | Date/Time | Comments
PPE worn as required
Laser cut PET | | | Number of face shields cut:
Assembly
Clean
Pack
Inspect | | | No. assemblies from batch
Box
Observations (including any rejects/problems arising)

Page of Face Visor Assembly SOP v2

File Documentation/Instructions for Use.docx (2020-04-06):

Disposable Visor

Directions For Use

To reduce contamination, store in the original plastic bag until use. This visor is single use and must be disposed of in the appropriate waste stream after use. It is not intended to be cleaned and cleaning products may cause deterioration.

One size fits all. 33cm x 23cm. Non-sterile.

Not for impact protection.

Made at Makespace Cambridge Ltd. for Cambridge University Hospitals

Contact Clinical Engineering Innovation for more information

Box 152

Cambridge University Hospitals

NHS Foundation Trust

Hills Road

Cambridge

CB2 0QQ

cei@addenbrookes.nhs.uk

01223 216719

Appendix

Existing product’s label

Disposable Face Shield

DIRECTIONS FOR USE: This product is designed and intended only as a shield of the face to avoid liquid splashing or splattering. This is a single use product. Dispose of Product after use.

One Size fits all. NON-STERILE. SIZE: 33cm x 23cm

THIS PRODUCT IS NOT CE-MARKED. IT IS ONLY FOR USE DURING THE COVID-19 OUTBREAK

Requirements for content:

Manufacturer's instructions and information

In addition to the name and address of the manufacturer, the instructions that must be supplied with the PPE must contain all relevant information on:

A. instructions for storage, use, cleaning, maintenance, servicing and disinfection. Cleaning, maintenance or disinfectant products recommended by manufacturers must have no adverse effect on the PPE or the user when applied in accordance with the relevant instructions;
  a. To reduce contamination, store in the original plastic bag until use. This visor is single use and must be disposed of in the appropriate waste stream after use. It is not intended to be cleaned and some cleaning products may cause deterioration.
B. performance as recorded during relevant technical tests to check the levels or classes of protection provided by the PPE;
  a. One size fits all. 33cm x 23cm. Non-sterile.
C. where applicable, accessories that may be used with the PPE and the characteristics of appropriate spare parts;
  a. none?
D. where applicable, the classes of protection appropriate to different levels of risk and the corresponding limits of use;
  a. not for impact protection.
E. where applicable, the month and year or period of obsolescence of the PPE or of certain of its components;
  a. Not sure what would expire?
F. where applicable, the type of packaging suitable for transport;
  a. N/A
G. the significance of any markings (see point 2.12);
  a. N/A
H. the risk against which the PPE is designed to protect;
  a. For protection against flying respiratory droplets and liquid splashes,
I. the reference to this Regulation and, where applicable, the references to other Union harmonisation legislation;
  a. Conforms to the intent of PPE Regulation EU 2016/425
J. the name, address and identification number of the notified body or bodies involved in the conformity assessment of the PPE;
  a. N/A
K. references to the relevant harmonised standard(s) used, including the date of the standard(s), or references to the other technical specifications used;
  a. N/A
L. the internet address where the EU declaration of conformity can be accessed.
  a. ?

The information referred to in points (i), (j), (k) and (l) need not be contained in the instructions supplied by the manufacturer if the EU declaration of conformity accompanies the PPE.

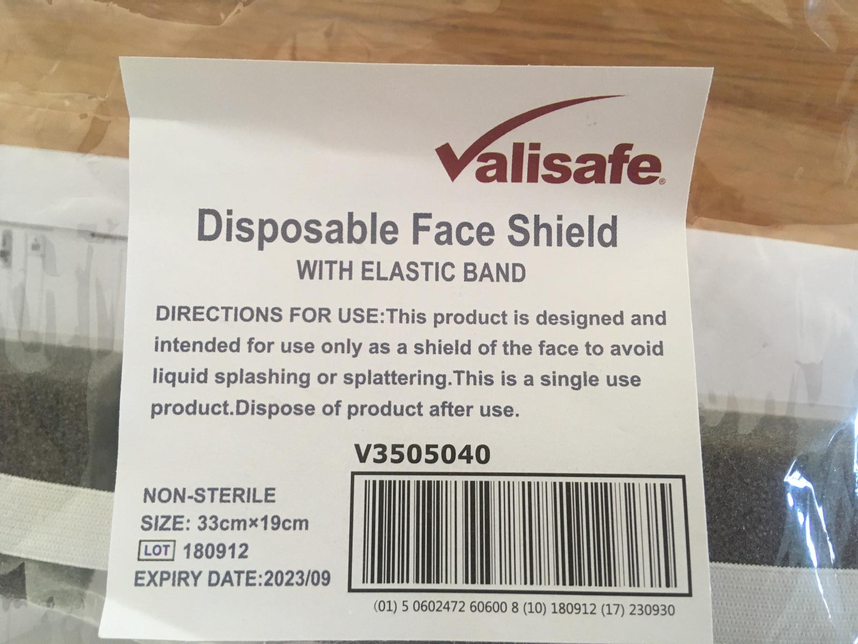
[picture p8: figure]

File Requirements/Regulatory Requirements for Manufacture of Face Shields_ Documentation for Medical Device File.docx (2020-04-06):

# Regulatory Requirements for Manufacture of Face Shields: Documentation for Medical Device File

1. Purpose

Face shields are NOT a medical device:

https://assets.publishing.service.gov.uk/government/uploads/system/uploads/attachment_data/file/284505/Borderlines_with_medical_devices.pdf

Masks intended to protect the wearer, they are regulated as personal protective equipment and need to meet the regulations covering PPE products:

https://eur-lex.europa.eu/legal-content/EN/TXT/?uri=CELEX:32016R0425

In the current coronavirus outbreak regulations have been temporarily suspended to fast-track supplies of PPE to NHS staff and protect companies hit by COVID-19. PPE equipment is allowed to be placed on the market providing protection against COVID-19 which lack the CE mark onto the market provided products meet essential safety requirements.

https://www.gov.uk/government/news/regulations-temporarily-suspended-to-fast-track-supplies-of-ppe-to-nhs-staff-and-protect-companies-hit-by-covid-19

2. Scope

This document sets out the requirements of the REGULATION (EU) 2016/425 OF THE EUROPEAN PARLIAMENT AND OF THE COUNCIL of 9 March 2016 on personal protective equipment and repealing Council Directive 89/686/EEC for face shields produced and manufactured by CEI for use within Addenbrookes to help prevent coronavirus (COVID-19)

This Regulation lays down requirements for the design and manufacture of personal protective equipment (PPE) which is to be made available on the market, in order to ensure protection of the health and safety of users and establish rules on the free movement of PPE in the Union.

As Clinical Engineering Innovation do not intend to place any of the manufactured devices on the market, a notified body will not be involved and a CE mark will not be obtained. However, the face shields will be designed and manufactured to meet the Essential Health and Safety Requirements set out in Annex II of the standard to ensure the safety of products entering the hospital.

3. Obligations of manufacturers

Article 8

Obligations of manufacturers

1. When placing PPE on the market, manufacturers shall ensure that it has been designed and manufactured in accordance with the applicable essential health and safety requirements set out in Annex II. See filled out list of EHSR below.

2. Manufacturers shall draw up the technical documentation referred to in Annex III (‘technical documentation’) and carry out the applicable conformity assessment procedure referred to in Article 19 or have it carried out. See notes on tech documentation

Where compliance of PPE with the applicable essential health and safety requirements has been demonstrated by the appropriate procedure, manufacturers shall draw up the EU declaration of conformity referred to in Article 15 and affix the CE marking referred to in Article 16. n/a - not placing on the market therefore no declaration of conformity

3. Manufacturers shall keep the technical documentation and the EU declaration of conformity for 10 years after the PPE has been placed on the market. Documentation to be placed on Q-Pulse

4. Manufacturers shall ensure that procedures are in place for series production to remain in conformity with this Regulation. Changes in the design or characteristics of the PPE and changes in the harmonised standards or in other technical specifications by reference to which the conformity of the PPE is declared shall be adequately taken into account.

When deemed appropriate with regard to the risks presented by PPE, manufacturers shall, to protect the health and safety of consumers and other end-users, carry out sample testing of PPE made available on the market, investigate, and, if necessary, keep a register of complaints, of non-conforming PPE and PPE recalls, and shall keep distributors informed of any such monitoring. See risk assessment - risks posed by PPE are low to end user

5. Manufacturers shall ensure that the PPE which they place on the market bears a type, batch or serial number or other element allowing its identification, or, where the size or nature of the PPE does not allow it, that the required information is provided on the packaging or in a document accompanying the PPE. See manufacturing SOP

6. Manufacturers shall indicate, on the PPE, their name, registered trade name or registered trade mark and the postal address at which they can be contacted or, where that is not possible, on its packaging or in a document accompanying the PPE. The address shall indicate a single point at which the manufacturer can be contacted. The contact details shall be in a language easily understood by end-users and market surveillance authorities. See manufacturing SOP

7. Manufacturers shall ensure that the PPE is accompanied by the instructions and information set out in point 1.4 of Annex II in a language which can be easily understood by consumers and other end-users, as determined by the Member State concerned. Such instructions and information, as well as any labelling, shall be clear, understandable, intelligible and legible. See instruction manual

8. The manufacturer shall either provide the EU declaration of conformity with the PPE or include in the instructions and information set out in point 1.4 of Annex II the internet address at which the EU declaration of conformity can be accessed. n/a

9. Manufacturers who consider or have reason to believe that PPE which they have placed on the market is not in conformity with this Regulation shall immediately take the corrective measures necessary to bring that PPE into conformity, to withdraw it or to recall it, as appropriate. Furthermore, where the PPE presents a risk, manufacturers shall immediately inform the competent national authorities of the Member States in which they made the PPE available on the market to that effect, giving details, in particular, of the non-conformity and of any corrective measures taken.

10. Manufacturers shall, further to a reasoned request from a competent national authority, provide it with all the information and documentation, in paper or electronic form, necessary to demonstrate the conformity of the PPE with this Regulation, in a language which can be easily understood by that authority. They shall cooperate with that authority, at its request, on any action taken to eliminate the risks posed by PPE which they have placed on the market.

4. Annex II: Essential Health and Safety Requirements

In addition to any of the measures specified in this document, a full risk assessment will be performed in order to identify the risks which apply to this PPE. This will include not only the intended use of the PPE, but also the reasonably foreseeable uses and where applicable, the health and safety of persons other than the user.

Essential Health and Safety Requirement | Method of fulfilment | Additional documentation (if applicable)

1. GENERAL REQUIREMENTS APPLICABLE TO ALL PPE
PPE must provide adequate protection against the risks against which it is intended to protect. | Face shields are designed to protect the face and eyes from liquid droplets that may contain viral particles. The plastic visors cover the full face and are impermeable to water. | Design documentation
1.1. Design principles 1.1.1. Ergonomics PPE must be designed and manufactured so that, in the foreseeable conditions of use for which it is intended, the user can perform the risk-related activity normally whilst enjoying appropriate protection of the highest level possible. | The face shields are made of clear plastic to allow the user full visibility to perform their activities whilst providing appropriate protection. | Requirements Specification Design Documentation User feedback
1.1.2. Levels and classes of protection 1.1.2.1. Optimum level of protection The optimum level of protection to be taken into account in the design is that beyond which the constraints imposed by the wearing of the PPE would prevent its effective use during the period of exposure to the risk or the normal performance of the activity. | The face shields are designed to be as large as possible to cover the entire face, without impacting activities. The flexible plastic allows for a close fit around the face and the foam along the top prevents droplets entering from above. Further attempts to make the design more fitted would limit the number of clinicians who it would fit and restrict normal activities. | Requirements Specification Design Documentation Risk File
1.1.2.2. Classes of protection appropriate to different levels of risk Where differing foreseeable conditions of use are such that several levels of the same risk can be distinguished, appropriate classes of protection must be taken into account in the design of the PPE. | Face shields are designed to meet the user requirements for use as specified by hospital guidance. Where specified in the hospital guidance and training documents additional or different PPE will be worn | Requirements Specification Design Documentation
1.2. Innocuousness of PPE 1.2.1. Absence of inherent risks and other nuisance factors PPE must be designed and manufactured so as not to create risks or other nuisance factors under foreseeable conditions of use. | Face masks are designed so that only a foam strip makes contact with the user's forehead. This is to maximise comfort and increase compliance. Face shields are designed to be similar to current PPE used by clinical staff in the hospital. | Requirements specification Design documentation User feedback
1.2.1.1. Suitable constituent materials The materials of which the PPE is made, including any of their possible decomposition products, must not adversely affect the health or safety of users. | Appropriate selection of materials and suppliers. Non toxic biocompatible materials selected. Materials will only make contact with non-broken skin. | Material Data sheets and supplier information
1.2.1.2. Satisfactory surface condition of all PPE parts in contact with the user Any part of the PPE that is in contact or is liable to come into contact with the user when the PPE is worn must be free of rough surfaces, sharp edges, sharp points and the like which could cause excessive irritation or injuries. | Plastic shields will be cut using a laser cutter and checked for rough or sharp edges. If found these will be filed down. | Manufacturing Work Instruction - Quality Check
1.2.1.3. Maximum permissible user impediment Any impediment caused by PPE to the actions to be carried out, the postures to be adopted and sensory perceptions shall be minimised. Furthermore, use of the PPE must not engender actions which might endanger the user. | Face shields will be designed to be similar to those that clinicians are already familiar with wearing. There shall be no increased impediments. Elastic straps will not be too tight that users will feel the need to reposition their face shields during use. They will not be too loose that the face shield could slip down. This will be tested on volunteers with a variety of head sizes | Requirements Specification Device Design Documentation Risk File User feedback
1.3. Comfort and effectiveness 1.3.1. Adaptation of PPE to user morphology PPE must be designed and manufactured in such a way as to facilitate its correct positioning on the user and to remain in place for the foreseeable period of use, bearing in mind ambient factors, the actions to be carried out and the postures to be adopted. For this purpose, it must be possible to adapt the PPE to fit the morphology of the user by all appropriate means, such as adequate adjustment and attachment systems or the provision of an adequate range of sizes. | The use of compressible foam strip and elastic strap allow the face shields to fit comfortably on users of varying morphology | Device Design Documentation Risk File User feedback - including test with small & large user
1.3.2. Lightness and strength PPE must be as light as possible without prejudicing its strength and effectiveness. PPE must satisfy the specific additional requirements in order to provide adequate protection against the risks for which it is intended and PPE must be capable of withstanding environmental factors in the foreseeable conditions of use. | The face shields are designed to protect users against liquid droplets. In typical use it is not anticipated that they will come into contact with any large mechanical forces. The plastic is therefore as thin as possible to be as light as possible and flex easily around the users head.The plastic will not shatter if a foreseeable force is applied. | Risk File Device Design Documentation Materials Data Sheets
1.3.3. Compatibility of different types of PPE intended for simultaneous use If the same manufacturer places on the market several PPE models of different types in order to ensure the simultaneous protection of adjacent parts of the body, they must be compatible. | n/a | User feedback - that it fits over googles, glasses, masks
1.3.4. Protective clothing containing removable protectors Protective clothing containing removable protectors constitutes PPE and shall be assessed as a combination during conformity assessment procedures. | n/a

1.4. Manufacturer's instructions and information

In addition to the name and address of the manufacturer, the instructions that must be supplied with the PPE must contain all relevant information on:

A. instructions for storage, use, cleaning, maintenance, servicing and disinfection. Cleaning, maintenance or disinfectant products recommended by manufacturers must have no adverse effect on the PPE or the user when applied in accordance with the relevant instructions;
B. performance as recorded during relevant technical tests to check the levels or classes of protection provided by the PPE;
C. where applicable, accessories that may be used with the PPE and the characteristics of appropriate spare parts;
D. where applicable, the classes of protection appropriate to different levels of risk and the corresponding limits of use;
E. where applicable, the month and year or period of obsolescence of the PPE or of certain of its components;
F. where applicable, the type of packaging suitable for transport;
G. the significance of any markings (see point 2.12);
H. the risk against which the PPE is designed to protect;
I. the reference to this Regulation and, where applicable, the references to other Union harmonisation legislation;
J. the name, address and identification number of the notified body or bodies involved in the conformity assessment of the PPE;
K. references to the relevant harmonised standard(s) used, including the date of the standard(s), or references to the other technical specifications used;
L. the internet address where the EU declaration of conformity can be accessed.

The information referred to in points (i), (j), (k) and (l) need not be contained in the instructions supplied by the manufacturer if the EU declaration of conformity accompanies the PPE.

See label on visor pack

Instructions for Use

2. ADDITIONAL REQUIREMENTS COMMON TO SEVERAL TYPES OF PPE
2.3. PPE for the face, eyes and respiratory system Any restriction of the user's face, eyes, field of vision or respiratory system by the PPE shall be minimised. The screens for those types of PPE must have a degree of optical neutrality that is compatible with the degree of precision and the duration of the activities of the user. If necessary, such PPE must be treated or provided with means to prevent misting-up. Models of PPE intended for users requiring sight correction must be compatible with the wearing of spectacles or contact lenses. | Face shields are transparent to allow for full visibility. Testing on volunteers to ensure that they do not fog up | Requirements Specification Device Design Documentation Risk file Materials Data sheets User feedback

3.10.2. Protection against cutaneous and ocular contact

PPE intended to prevent the surface contact of all or part of the body with substances and mixtures which are hazardous to health or with harmful biological agents must be capable of preventing the penetration or permeation of such substances and mixtures and agents through the protective integument under the foreseeable conditions of use for which the PPE is intended.

To this end, the constituent materials and other components of those types of PPE must be chosen or designed and incorporated so as to ensure, as far as possible, complete leak-tightness, which will allow where necessary prolonged daily use or, failing this, limited leak-tightness necessitating a restriction of the period of wear.

Where, by virtue of their nature and the foreseeable conditions of their use, certain substances and mixtures which are hazardous to health or harmful biological agents possess high penetrative power which limits the duration of the protection provided by the PPE in question, the latter must be subjected to standard tests with a view to their classification on the basis of their performance. PPE which is considered to be in conformity with the test specifications must bear a marking indicating, in particular, the names or, in the absence of the names, the codes of the substances used in the tests and the corresponding standard period of protection. The manufacturer's instructions must also contain, in particular, an explanation of the codes (if necessary), a detailed description of the standard tests and all appropriate information for the determination of the maximum permissible period of wear under the different foreseeable conditions of use.

Face shields are designed to protect the face and eyes from liquid droplets that may contain viral particles. The plastic visors cover the full face and are impermeable to water.

Risk File

5. Annex III: Technical Documentation for PPE

The technical documentation shall include at least the following elements:

(a) | a complete description of the PPE and of its intended use; Device Specification

(b) | an assessment of the risks against which the PPE is intended to protect; Risk File

(c) | a list of the essential health and safety requirements that are applicable to the PPE; Completed list of EHPR above

(d) | design and manufacturing drawings and schemes of the PPE and of its components, sub-assemblies and circuits; OPEN SOURCE FACE SHIELD DRAWING

(e) | the descriptions and explanations necessary for the understanding of the drawings and schemes referred to in point (d) and of the operation of the PPE; OPEN SOURCE FACE SHIELD DRAWING

(f) | the references of the harmonised standards referred to in Article 14 that have been applied for the design and manufacture of the PPE. In the event of partial application of harmonised standards, the documentation shall specify the parts which have been applied; n/a

(g) | where harmonised standards have not been applied or have been only partially applied, descriptions of the other technical specifications that have been applied in order to satisfy the applicable essential health and safety requirements; Complete list of EHSR above. Device Specification

(h) | the results of the design calculations, inspections and examinations carried out to verify the conformity of the PPE with the applicable essential health and safety requirements; Device Validation

(i) | reports on the tests carried out to verify the conformity of the PPE with the applicable essential health and safety requirements and, where appropriate, to establish the relevant protection class; Device Validation

(j) | a description of the means used by the manufacturer during the production of the PPE to ensure the conformity of the PPE produced with the design specifications; Manufacturing Work Instruction - Quality Check

(k) | a copy of the manufacturer's instructions and information set out in point 1.4 of Annex II;

(l) | for PPE produced as a single unit to fit an individual user, all the necessary instructions for manufacturing such PPE on the basis of the approved basic model; n/a

(m) | for PPE produced in series where each item is adapted to fit an individual user, a description of the measures to be taken by the manufacturer during the fitting and production process to ensure that each item of PPE complies with the approved type and with the applicable essential health and safety requirements. n/a

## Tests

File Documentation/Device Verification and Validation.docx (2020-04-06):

# Device Verification and Validation

1. Purpose

This document demonstrates that the finished devices meet the device specifications and the Essential Health and Safety Requirements as detailed in documents:

Essential Health and Safety Requirements: Face Shields

Requirements Specification

2. Scope

This document details the methods and results of the testing required to ensure the safety of the product.

3. Testing

Verification testing was performed against the requirements specification and in comparison to current face shields used within Addenbrookes.

User feedback was obtained from clinicians to ensure:

- Ergonomics of face shields
- Innocuousness of PPE

Testing on volunteers with a variety of head sizes was conducted to ensure that:

- The use of compressible foam strip and elastic strap allow the face shields to fit comfortably on users of varying morphology
- Elastic straps will not be too tight that users will feel the need to reposition their face shields during use. They will not be too loose that the face shield could slip down
- Face shields do not fog up during typical use

Volunteers with a variety of head sizes wore the face shields for 4 hours to mimic the longest length of time that a clinician would be expected to remain in full PPE during clinical activities. During this time they performed moderate exercise indoors to mimic clinical use. The face shields were also tested over glasses and FFP3 masks.

4. Results

User Need | Specification | Current face shield (Valisafe) | DELVE design
1. Single elasticated strap accommodates range of head sizes | n/a | PASS | PASS
2. Can be donned and doffed single handed | n/a | PASS | PASS
3. Face shields must fit snugly to afford a good seal to the forehead area - forehead contact at least width of eyes. | Compressible Brow foam, length > 20 cm | Compressible brow foam, length: 25 cm PASS | Compressible brow foam, length: 23 cm PASS
3. Contact surface soft foam or rubber, to reduce slippage during wearing. 5. Face shields should seal to the forehead | Compressible Brow foam | PASS | PASS
4. Visors must not significantly distort vision. | Normal font size text should be readable whilst wearing them. | PASS | PASS
5.Face shields should reach down to the chin and to the point of the ear, | Minimum size of plastic shield: 33cm by 19 cm | 33cm by 19 cm PASS | 33 cm by 23 cm PASS
6. The face should be sufficiently rigid to not move around (creating noise or distortion) whilst walking. Plastic shield flexible to bend around face comfortably and conform to forehead | n/a | PASS | PASS
7. Edges not sharp nor easily caught | Rounded corners. No burrs. | PASS | PASS
8. The visor should have sufficient clearance to the face for goggles and a face mask to be worn comfortably. | Foam depth >= 25mm | Foam depth: 30 mm PASS | Foam Depth:25mm PASS
9. Visors should be resistant to fogging, either through coatings or ventilation. | Does not fog up during 4 hours of use. Tested with user with a FFP3 mask | - | PASS
10.The face shield is single use so does need to be sterilisable or resistant to cleaning products | Labeled for single use | PASS | PASS

Clinical feedback demonstrated that the face shields were fit for purpose. Signed prescription forms can be found in the device file

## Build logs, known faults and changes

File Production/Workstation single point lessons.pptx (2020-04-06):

## Single Point Lessons

Work Station for DELVE Full Face Shield manufacture
See also ‘Manufacturing SOP’ for source content

Approved: Ward Hills

Date: 01 April 2020

## PET film Visor preparation for assembly

SAFETY: Handling IPA, eye protection

QUALITY: No scratches on the PET Film, all dust removed

Steps
1. Ensure the PET has its traveler with it
2. Check the lasered edge for sharpness or burning with a gloved finger - glove should not snag
3. Place visor onto a clean, soft, non shedding surface
4. Wipe gently with a tissue moistened with cleaning solution or IPA, removing all laser cutting dust. Make a maximum of FOUR light strokes
5. Reverse and repeat 3. and 4. for side 2
6. Place carefully into the WIP box
7. Book the operation into the batch record system (Chromebook).
8. Write an A5 traveler with the job number and your initials. Place into WIP box. Remove the incumbent traveler.

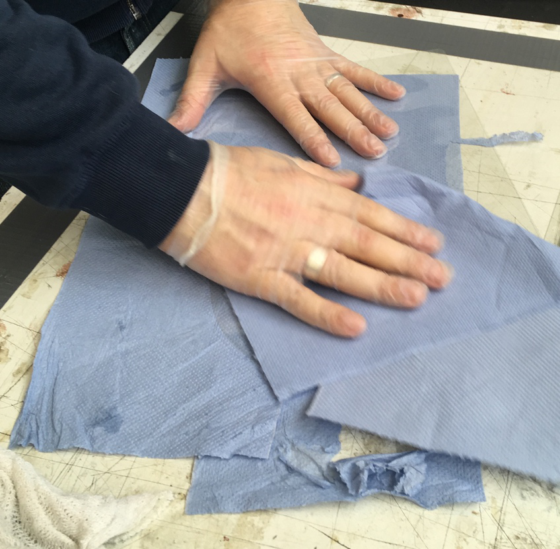
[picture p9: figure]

Approved: Ward Hills

Date: 01 April 2020

## Foam Prep

QUALITY: Adhesive backing should be full width of cut block.
Part to be cut to size and square

SAFETY: Bandsaw, Induction trained.

Steps
1. Ensure the Foam has its traveler with it
2. Set guide fence to 23.5cm. Cut on the bandsaw. Set to 2.8cm. Cut. Ensure block is against guide fence at all times
3. Remove any excess dust
4. CHECK: adhesive layer runs full width and length of the block
5. Place into a WIP box
6. Book the operation into the batch record system (Chromebook)
7. Write an A5 traveler with the job number and your initials. Place into WIP box. Remove the incumbent traveler

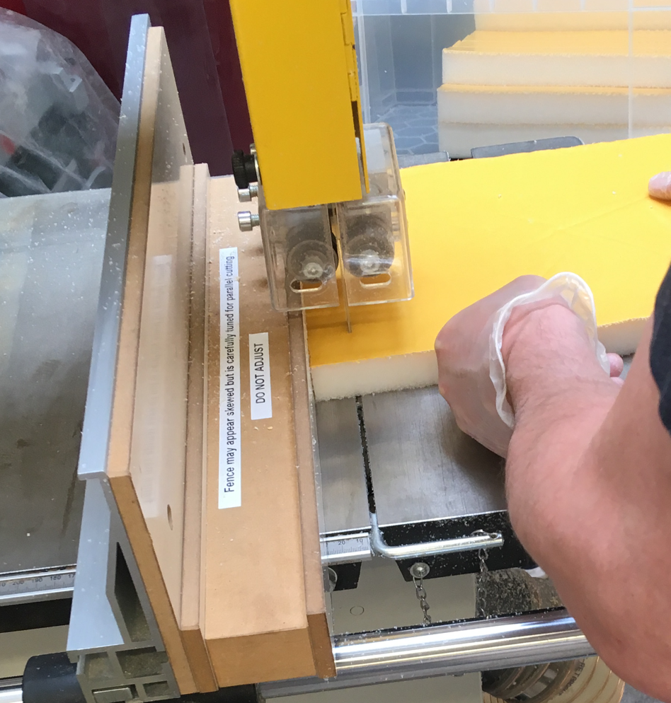
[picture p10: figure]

Approved: Ward Hills

Date: 01 April 2020

## Elastic Prep

SAFETY: None

QUALITY: Correct Length
Cut needs to be Square across web

Steps
1. Ensure the Elastic has its traveler with it
2. Measure to length
3. Cut with sharp scissors
4. Remove any fraying edges (Fine full width fibres)
5. Place into WIP box
6. Book the operation into the batch record system (Chromebook)
7. Write an A5 traveler with the job number and your initials. Place into WIP box. Remove the incumbent traveler

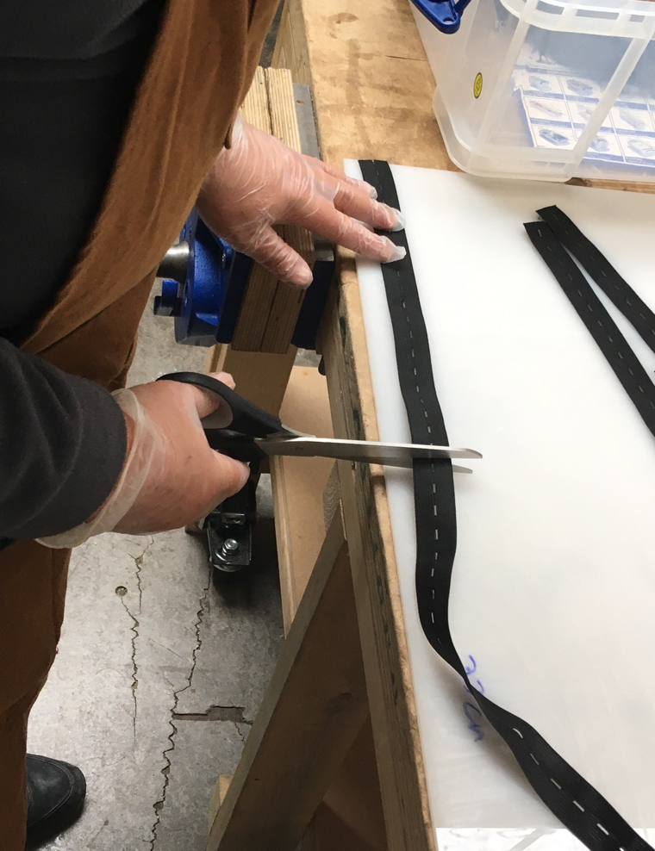
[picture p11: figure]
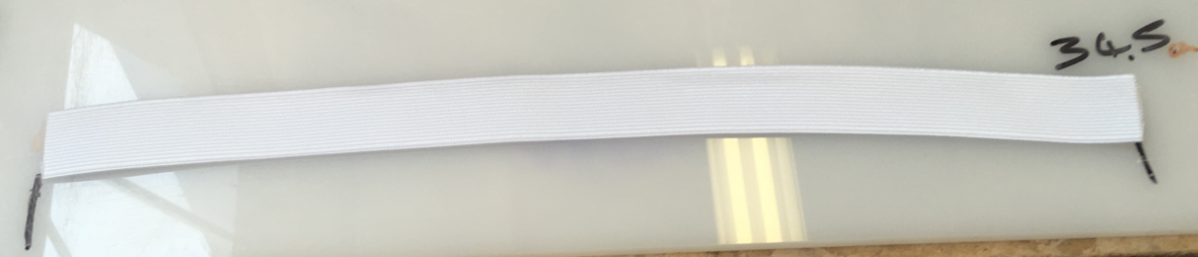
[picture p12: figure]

Approved: Ward Hills

Date: 01 April 2020

## Foam-PET Assembly

SAFETY: Sharp blade required

QUALITY: Foam fits in correct position. Foam fully attached. Foam adhesive not above PET visor edge

Steps
1. Ensure the Foam and PET have travelers. Where two batches are present, use the lowest job number first
2. Ensure the jig is clear of debris
3. Place the PET into the jig
4. Remove the release paper from the foam with a knife point
5. Place the foam onto the PET
6. Place into a WIP box
7. Book the operation into the batch record system (Chromebook)
8. Write an A5 traveler with the job number and your initials. Place into WIP box. Remove the incumbent traveler

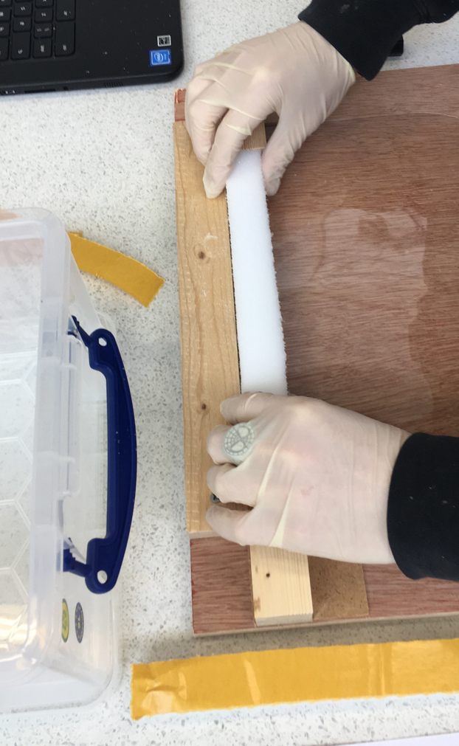
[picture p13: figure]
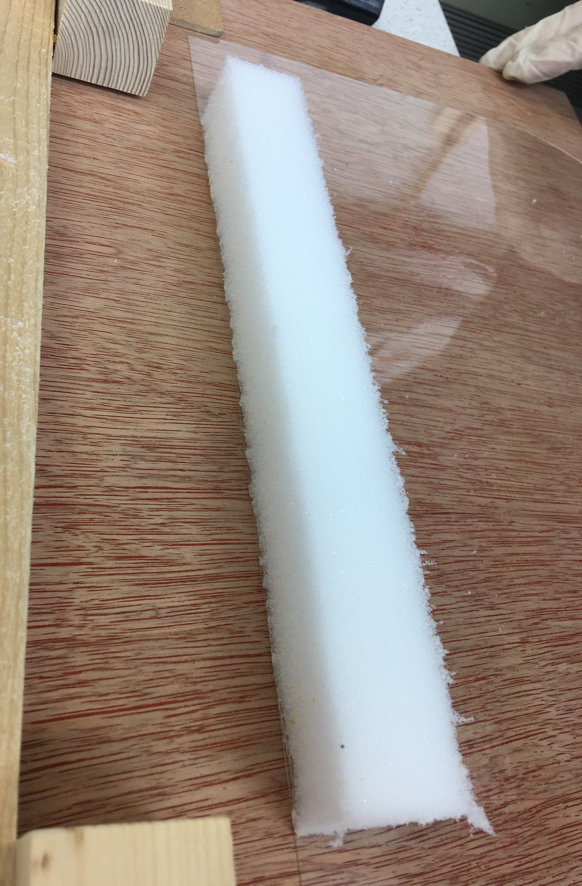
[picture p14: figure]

Approved: Ward Hills

Date: 01 April 2020

## Elastic Stapling

SAFETY: Stapler action

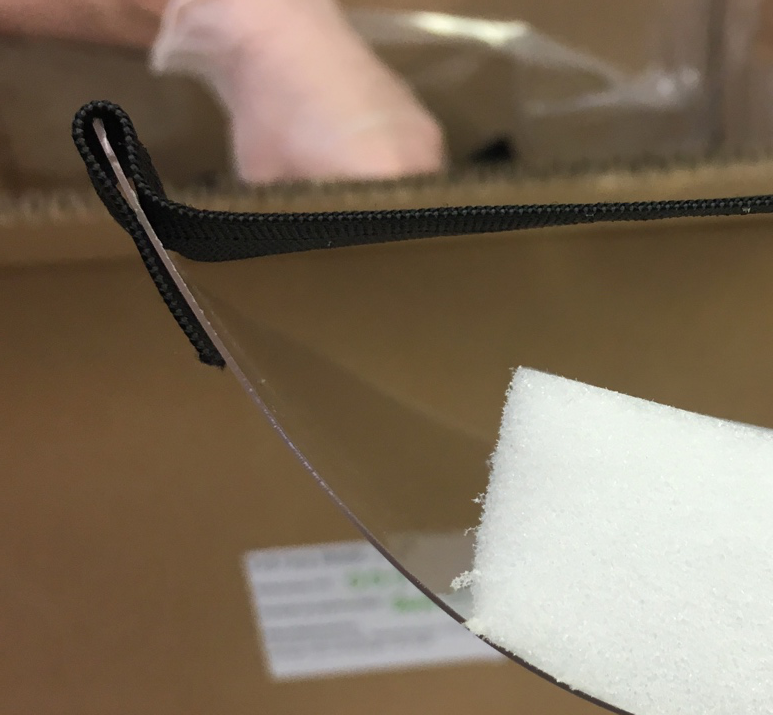
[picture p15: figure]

QUALITY: Correct elastic routing.
Staple fully formed, no sharp points

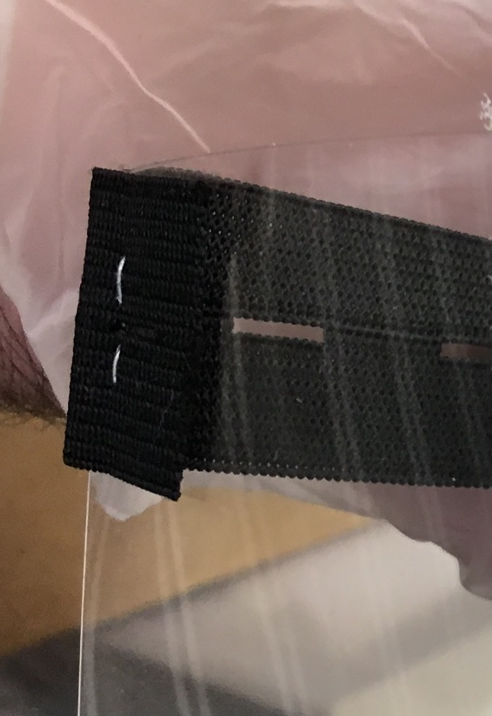
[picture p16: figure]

OUTSIDE

Steps
1. Ensure the cut Elastic and visor have travelers. Where two batches are present, use the lowest number first
2. Route elastic as shown, with end on OUTSIDE of visor
3. Staple through once from the INSIDE of the mask
4. Repeat 2. and 3. at the other side
5. Place into a WIP box
6. Book the operation into the batch record system (Chromebook)
7. Write an A5 traveler with the job number and your initials. Place into WIP box. Remove the incumbent traveler

1 cm

1 cm

INSIDE

OUTSIDE

Approved: Ward Hills

Date: 01 April 2020

## QA and Packing

QUALITY: Visor Scratches;
Visor edge NOT sharp;
Elastic length;
Fully stapled and NOT sharp Foam; Foam Adhesive full width;
No foam overhang top of visor

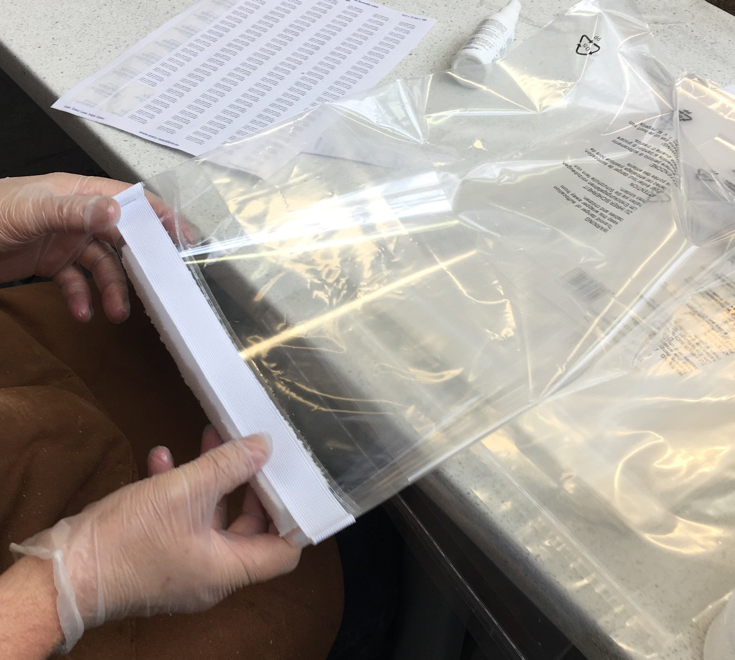
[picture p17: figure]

SAFETY: None

Steps
1. Ensure completed shields have a traveler
2. Make up a carton. Apply its label (MS-xxx)
3. Place the shield onto the packet of bags, spray with demister and wipe with a cloth
4. Reverse and repeat 3. on other side
5. Perform checks, as per the checklist at the station
6. Record QA FAIL jobs one-at-a-time on the batch record system. Place into reject bin
7. Apply both labels to the PASSED shield. Use the MS-xxx/zz labels to match the Carton label
8. Bag the shield
9. Place into the carton. Repeat for the batch
10. Add Shields from the “TOP UP” box to make 24-off Carton Quantity
11. Book the PASS operation into the batch record system (Chromebook). Note on job card if units taken from “TOP UP” box
12. Remove the incumbent traveler. Write an A5 traveler with the job number and your initials. Masking tape onto the Carton

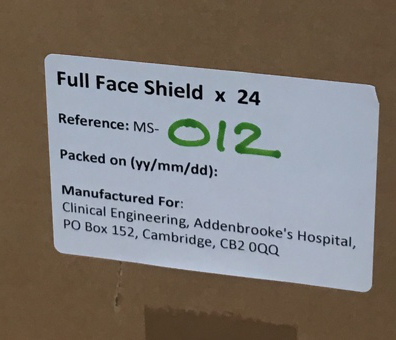
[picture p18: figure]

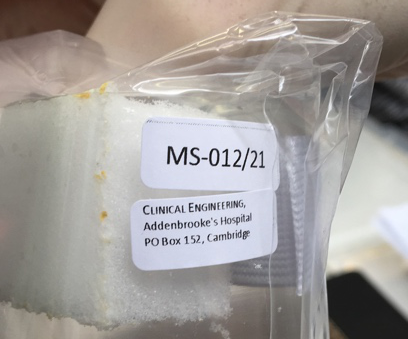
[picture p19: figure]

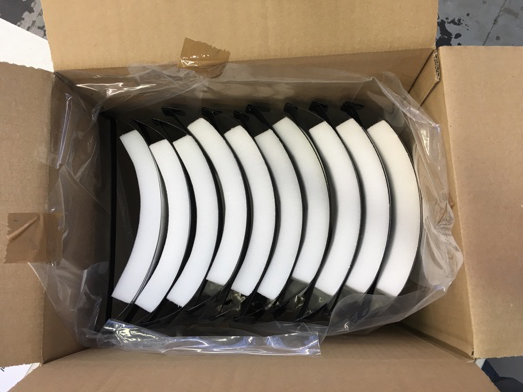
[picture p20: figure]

Approved: Ward Hills

Date: 01 April 2020

## Carton (Boxing)

SAFETY: None

QUALITY: MS-xxx Carton and Shield labels match
Shields are packed correctly in carton

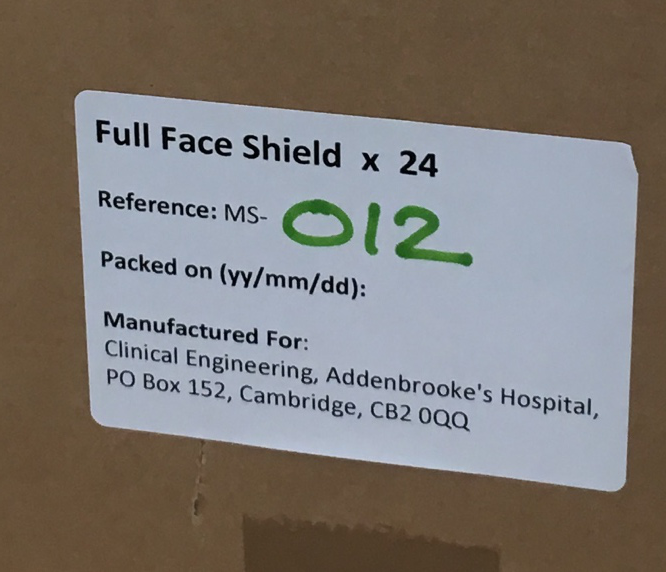
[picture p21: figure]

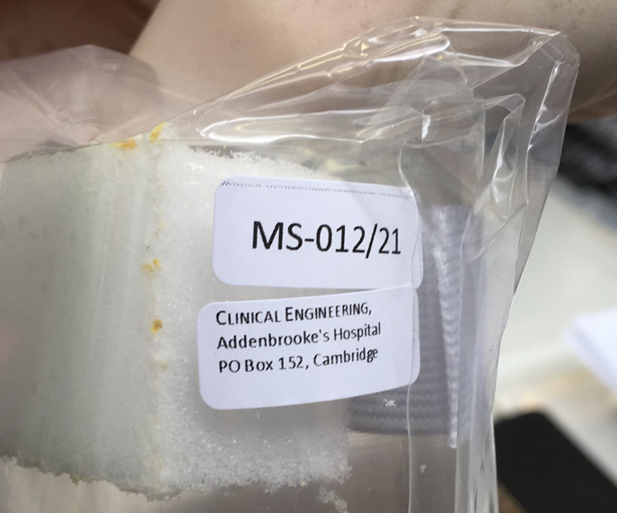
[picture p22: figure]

Steps
1. Ensure carton has a QA traveler taped to it
2. Check the Carton and Shield MS-xxx numbers match
3. Place Instructions For Use sheet inside Carton
4. Close up the Carton
5. Book the operation into the batch record system (Chromebook)

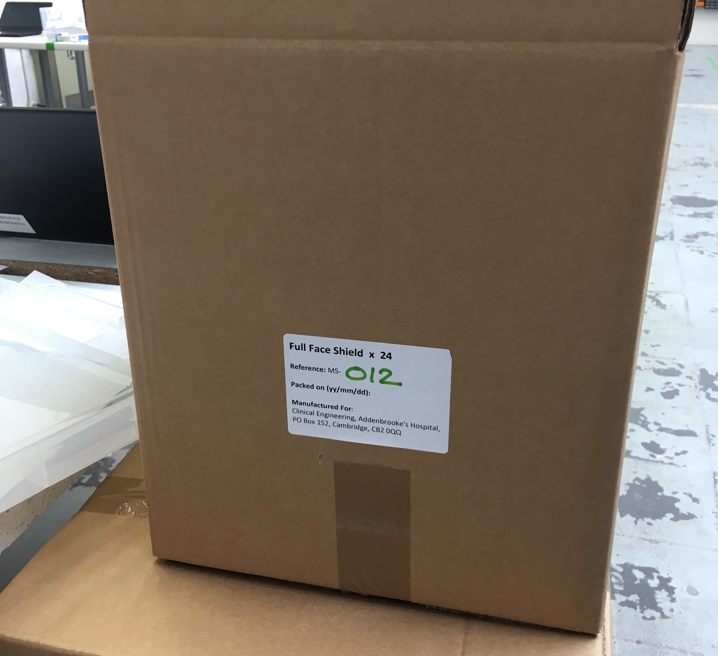
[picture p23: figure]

Approved: Ward Hills

Date: 01 April 2020

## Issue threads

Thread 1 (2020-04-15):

Lot numbers not unique, missing in Tracking workbook

pekka-28, 2020-04-15:
I have tried to analyse some of the data in the Tracking workbook and found a number of data items that don't make sense.

There are several Lot numbers that are duplicated in the workbook in adjacent to each other. The timing is around a minute apart, and the workstation is the same. This looks to be duplicated data capture. I'm not clear whether the number if meant to be a primary key, or some kind of rough relative ordering indicator so can't say if this is significant.

I also note that several of the Void workstation lots have a dependency with the value -1. Since this lot does not exist in the database, I noticed this in a foreign key relationship error.

After some massaging, I created the attached image for the first day of data. This could be helpful in understanding non-standard operation sequences in the event of problems. For example, it looks like the Boxing node is using the incorrect traceability lot information.

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

axiomsofchoice, 2020-04-15:
The data in the `JobLog` sheet of `Tracking - Workers, Goods, Jobs.xlsx` represents an early snapshot of the data. It's important to understand how these data were collected. Originally there was just a spreadsheet but it rapidly became clear that errors would easily creep in so a [web app](https://github.com/axiomsofchoice/jobcardsystem) was created to eliminate these as far as possible. For instance, making it only possible to select up-stream job cards that were both of the right type and still marked as WIP. Over time this improved data quality but some manual intervention was still required at times. For a while we saw double entries because the Google servers were slow to response so users clicked until they received a response. Duplicates were marked `Void`, as documented [here](https://github.com/axiomsofchoice/jobcardsystem#guidance-for-admins). This artifact was eliminated by disabling the submit button after the first click. As part of the [`reporting.py`](https://github.com/axiomsofchoice/jobcardsystem#reporting) tool it's possible to discover exactly the inconsistencies in dependencies you highlight here and manually fix them.  Now that production has finished it's possible to provide an updated version with the issues you've identified fixed and I'll ask if this is possible, following appropriate anonymization. I'm impressed with the graph you've come up with! Those dependencies should really look like [this](https://github.com/axiomsofchoice/jobcardsystem/blob/dc2df42d65eb95329684bf60aed9f6e3ece49720/reporting/reporting.py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). If you like graphs why not try `reporting.py --graph` and please share any results of analyses you come up with :)

pekka-28, 2020-04-15:
That is much what expected. I see the Python code also uses Graphviz for the rendering. I have used the [ProM process mining toolkit ](http://www.promtools.org/doku.php) for this kind of analysis in the past. One of the helpful use cases is that the tool can identify uncommon flows. This usually indicates a work-around in a production environment and is often worth investigation.

axiomsofchoice, 2020-04-15:
I wasn't aware of that toolkit. Thanks for sharing!

Closed 2020-04-15.
